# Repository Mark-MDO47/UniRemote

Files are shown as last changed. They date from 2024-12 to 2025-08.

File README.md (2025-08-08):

# UniRemote - one remote to rule them all!
I wanted a way to control all the projects I make.
- Note: it is not a remote for A/V systems. It is for my projects.

I wanted this to work not just at home in my WiFi zone but also at remote locations like a Maker Faire.<br>
It communicates with my projects via ESP-NOW WiFi
- https://docs.espressif.com/projects/esp-idf/en/stable/esp32/api-reference/network/esp_now.html

Current state of software and tools: **v1.0** "basics work: CYD, Tiny Code Reader for QRcodes, Mifare RC522 RF IC via MicroSD sniffer for 13.56MHz MIFARE Classic 1K cards, XPT2046_Bitbang lib to free up VSPI"

Here is a short YouTube demonstration of the latest version
- https://youtu.be/a9atNTkQOKo

This is the UniRemoteCYD breadboard setup with "drone style" batteries.
- I removed the QR code reader since the RFID reader was so easy to use
- The contactless RFID PICC cards (Proximity Integrated Circuit Card) are to the left
- The "drone style" battery charger and charging cable is at the top
- The XAIO ESP32-Sense target processor is below that, attached to a USB cable
- The Cheap Yellow Display (CYD) and its RFID sensor and batteries are on the bottom right
  - The red board sticking out at the bottom is the MicroSD Sniffer card used to communicate with the RFID sensor
- You can see more photos at https://github.com/Mark-MDO47/UniRemote/blob/master/photos.md
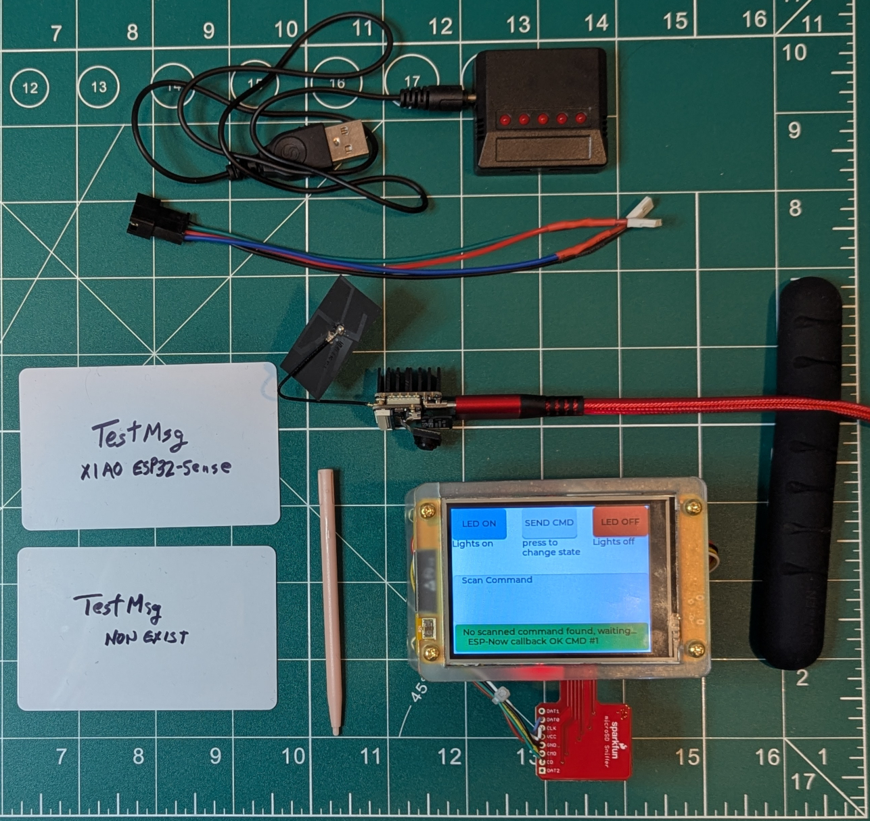
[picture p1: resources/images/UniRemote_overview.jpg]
Image of UniRemote breadboard overview


A little comic relief - the hilarious **Legendary Artifacts Club** by Elle Cordova https://www.youtube.com/shorts/GEJ_KPZY4n4

| One Remote to Rule Them All | I can bend countless devices to my will |
| --- | --- |
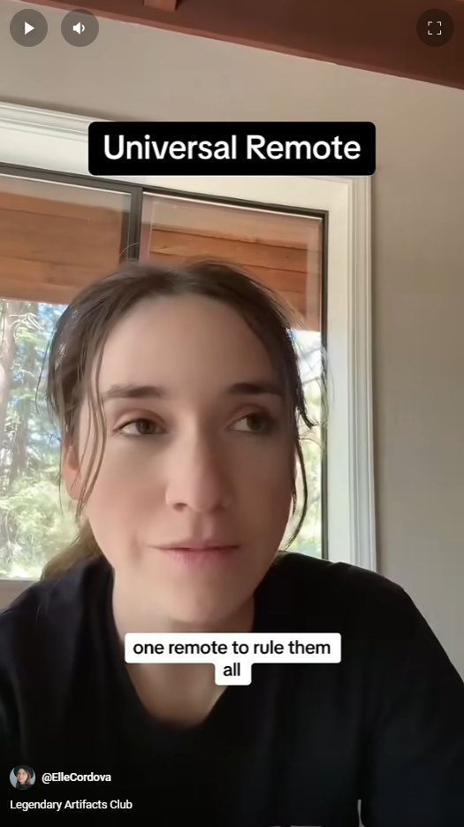
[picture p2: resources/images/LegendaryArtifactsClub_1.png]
Legendary Artifacts Club by Elle Cordova
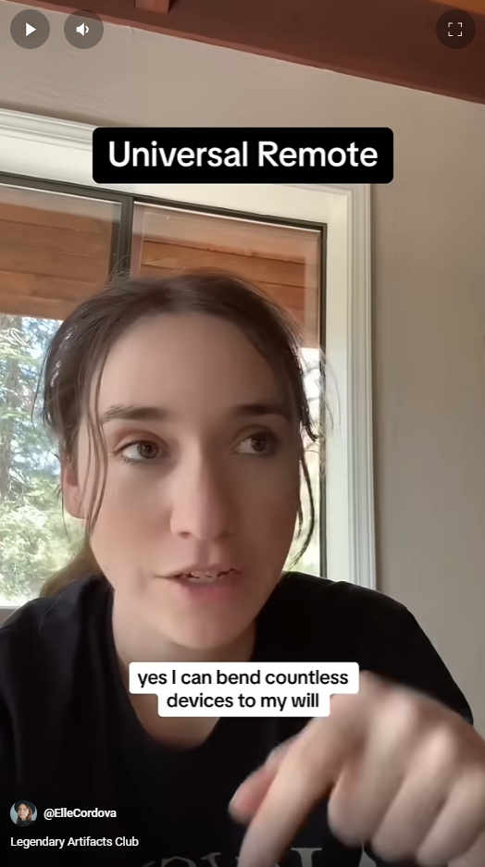
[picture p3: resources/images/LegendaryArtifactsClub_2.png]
Legendary Artifacts Club by Elle Cordova
|  |  |

**Table Of Contents**
* [Top](#uniremote-\--one-remote-to-rule-them-all "Top")
* [The Plan](#the-plan "The Plan")
* [Guide to the Code](#guide-to-the-code "Guide to the Code")
* [Schematic](#schematic "Schematic")
  * [Battery Harness](#battery-harness "Battery Harness")
* [Parts List](#parts-list "Parts List")
* [Interesting Considerations](#interesting-considerations "Interesting Considerations")
  * [General CYD and LVGL and Related Info](#general-cyd-and-lvgl-and-related-info "General CYD and LVGL and Related Info")
  * [DRAM_STR - Move Constant Strings to RAM instead of Program Storage](#dram_str-\--move-constant-strings-to-ram-instead-of-program-storage "DRAM_STR - Move Constant Strings to RAM instead of Program Storage")
  * [Entire Screen Pans or Scrolls](#entire-screen-pans-or-scrolls "Entire Screen Pans or Scrolls")
  * [LVGL Timeout and Crash if Call LVGL Routine inside ESP-NOW callback](#lvgl-timeout-and-crash-if-call-lvgl-routine-inside-esp\-now-callback "LVGL Timeout and Crash if Call LVGL Routine inside ESP-NOW callback")
  * [Do-It-Yourself Layout Creator](#do\-it\-yourself-layout-creator "Do-It-Yourself Layout Creator")
* [Licensing](#licensing "Licensing")

## The Plan
[Top](#uniremote-\--one-remote-to-rule-them-all "Top")<br>
My current thinking is to just use the RFID reader and leave out the QR code reader. Maybe add it back in later.

Because the MicroSD sniffer sticks out so far, I had planned to use removable 18650 batteries mounted on the side of the CYD to give it some protection. However, putting the 18650 batteries on the outside was trickier than I thought due to some connectors and components getting in the way. It also didn't provide much protection for the sniffer. I went ahead and put the Lipo "drone style" batteries in for now. There is a connector that allows me to charge the Lipo batteries without removing them.
- More details in the section [Battery Harness](#battery-harness "Battery Harness")

I have settled on the following hardware for the Universal Remote Control:
- CYD - Cheap Yellow Display
  - I am using the ESP32-2432S028R (Cheap Yellow Display or CYD) based on ESP32-D0WDQ6 controller.
  - I purchased this one: https://www.aliexpress.us/item/3256805697430313.html
  - This schematic might reflect the CYD: https://oshwlab.com/mariusmym/esp32_cyd_cheap_yellow_display
  - This gives an excellent CYD introduction: https://randomnerdtutorials.com/esp32-cheap-yellow-display-cyd-pinout-esp32-2432s028r
- RFID Reader
  - I am using the HiLetgo 3pcs RFID Kit - Mifare RC522 RF IC Card Sensor Module + S50 Blank Card + Key Ring
    - I purchased this one: https://www.amazon.com/dp/B07VLDSYRW
    - This doesn't support I2C or UART without board modifications; just SPI
      - look for Adrianotiger post #4 on Mar 2023 on https://forum.arduino.cc/t/esp32-rfid-rc522-i2c/1100200/3
      - here is webpage for the module including schematic https://www.sunrom.com/p/rfid-readerwriter-1356mhz-rc522-spi-module-with-cardkeychain
  - I am using the Meikuler 13.56MHz MIFARE Classic 1K, RFID Smart Cards / M1 Cards, ISO14443A Printable Blank RFID PVC Cards
    - I purchased this one: https://www.amazon.com/dp/B07S63VT7X
    - https://www.nxp.com/docs/en/data-sheet/MF1S50YYX_V1.pdf
    - A.K.A. PICC = Proximity Integrated Circuit Card (Contactless Card)
  - See following for more RFID Reader details:
    - https://github.com/Mark-MDO47/UniRemote/tree/master/code/RFIDRC522test
  - It took a bit of effort to use this with the CYD. I got a "sniffer" card to use the SPI pins in the CYD MicroSD slot, needed to do "bit banging" for touchscreen so could use hardware SPI for SD card.
    - I purchased this one: https://www.sparkfun.com/sparkfun-microsd-sniffer.html
    - https://github.com/sparkfun/MicroSD_Sniffer
    - Schematic https://cdn.sparkfun.com/datasheets/Tools/SparkFun_MicroSD_Sniffer_v10.pdf
    - https://github.com/Mark-MDO47/UniRemote/blob/master/code/RFIDRC522test/README.md

Will be trying these to see if they can be a more compact MicroSD sniffer:
- Nope: Extender cable 1: https://www.aliexpress.com/item/3256804754907124.html
- Nope: Extender cable 2: https://www.aliexpress.com/item/3256805782352551.html
- Nope: Alternative MicroSD sniffer to JTAG: https://shop.blinkinlabs.com/products/microsd-to-jtag-adapter-for-esp32

May use one or more of the following
- QR code reader
  - Tiny Code Reader from Useful Sensors
  - I purchased this one: https://www.sparkfun.com/products/23352
  - https://cdn.sparkfun.com/assets/e/9/d/9/f/TCR_Datasheet.pdf
  - https://github.com/usefulsensors/tiny_code_reader_docs/blob/main/README.md
  - https://github.com/usefulsensors/tiny_code_reader_arduino
- Alternative QR code readers
  - https://github.com/IndustrialArduino/NORVI-ESP32-CAMERA/tree/main/ESP32-CAMERA-QR_CODE_SCANNER_WITH_DISPLAY
  - https://randomnerdtutorials.com/esp32-cam-qr-code-reader-scanner-arduino/
- Voice Input - perhaps one of these
  - https://www.seeedstudio.com/XIAO-ESP32S3-Sense-p-5639.html
  - https://www.dfrobot.com/product-2665.html
- Joystick or rotary encoder, buttons
- BlueTooth keyboard

The hardware that receives the commands can use basically any ESP32 that includes WiFi.

## Guide to the Code
[Top](#uniremote-\--one-remote-to-rule-them-all "Top")<br>
Here is what the code is:<br>
| Link | Description |
| --- | --- |
| --- | **UNIREMOTE CODE** |
| [code/UniRemoteCYD](https://github.com/Mark-MDO47/UniRemote/tree/master/code/UniRemoteCYD "UniRemoteCYD") | "Cheap Yellow Display"-based UniRemote code sending ESP-NOW commands - attributions in the code.<br>Commands are input with either the QR code reader (I2C) or the RFID Reader (SPI via MicroSD sniffer).<br>To free up access to the CYD hardware VSPI port for the RFID Reader, the code uses the XPT2046_Bitbang software-based SPI library instead of the TFT_eSPI hardware based SPI library for the touchscreen.<br>This technique of using XPT2046_Bitbang for the touchscreen could alternatively be used to access the MicroSD card on the CYD if the MicroSD pins weren't being used for the RFID Reader. |
| [code/Uni_RW_PICC](https://github.com/Mark-MDO47/UniRemote/tree/master/code/Uni_RW_PICC "Uni PICC Rd/Wr") | UniRemote PICC read/write routines - attribution in the README |
| [code/CYDbitBangCalibrate](https://github.com/Mark-MDO47/UniRemote/tree/master/code/CYDbitBangCalibrate "CYDbitBangCalibrate") | Modified Random Nerds CYD Calibrate routine that uses the XPT2046_Bitbang software-based SPI library instead of the TFT_eSPI hardware based SPI library for the touchscreen - attributions in the code |
| [code/tiny_code_reader](https://github.com/Mark-MDO47/UniRemote/tree/master/code/tiny_code_reader "tiny_code_reader") | *.h file for using the QR code reader - attribution in its README<br>NOTE: not currently used in UniRemoteCYD |
| --- | **RECEIVER CODE** |
| [code/UniRemoteRcvrTemplate](https://github.com/Mark-MDO47/UniRemote/tree/master/code/UniRemoteRcvrTemplate "UniRemoteRcvrTemplate") | UniRemote code **template** for generic receiver of the commands - attributions in the code.<br>UniRemoteRcvrTemplate.ino shows an example of using UniRemoteRcvr.h and UniRemoteRcvr.cpp to receive ESP-NOW commands from UniRemoteCYD.<br>Also includes my adaptation of the ESP32 example **OTAWebUpdater.ino** Over-The-Air web updater **mdo_use_ota_webupdater**. |
| [code/mdo_use_ota_webupdater](https://github.com/Mark-MDO47/UniRemote/blob/master/code/mdo_use_ota_webupdater "mdo_use_ota_webupdater") |  My adaptation of the ESP32 example **OTAWebUpdater.ino** Over-The-Air web updater **mdo_use_ota_webupdater**. |
| [code/readMacAddress](https://github.com/Mark-MDO47/UniRemote/tree/master/code/readMacAddress "readMacAddress") | Code to read the WiFi MAC address of pretty much any ESP32 - used on remotes to get info - attribution in its README |
| --- | **UTILITIES** |
| [code/WriteRFID](https://github.com/Mark-MDO47/UniRemote/tree/master/code/WriteRFID "WriteRFID") | Used to **write** RFID cards using input text strings in same format as input to QRCode.py or **read** RFID cards - attributions in the code.<BR>Works on both UniRemoteCYD hardware and EPS32D special purpose hardware. |
| [MDOpythonUtils QRCode.py](https://github.com/Mark-MDO47/MDOpythonUtils/tree/master/QRCode "QRCode.py") | Python routine to generate QR code based on directions in a text file |
| --- | **DOCUMENTATION** |
| [code/CYDtest](https://github.com/Mark-MDO47/UniRemote/tree/master/code/CYDtest "CYDtest") | ESP32-2432S028R (Cheap Yellow Display or CYD) pointers to tutorials and hardware information |
| [code/RFIDRC522test](https://github.com/Mark-MDO47/UniRemote/tree/master/code/RFIDRC522test "RFIDRC522test")  | RFID RC522 pointers to tutorials and hardware information |
| --- | **DEPRECATED** |
| [code/UniRemote](https://github.com/Mark-MDO47/UniRemote/tree/master/code/UniRemote "UniRemote") | UniRemote code with QR code reader and **generic ESP32** module - attributions in the code. This is now **unused** and **deprecated**. I am switching to the CYD and the code in **UniRemoteCYD**. |
| [code/UniTestRcvr](https://github.com/Mark-MDO47/UniRemote/tree/master/code/UniTestRcvr "UniTestRcvr") | UniRemote code testbench for receiver of the commands - attributions in the code. This is now **unused** and **deprecated**. All further development for the receiver will go to the generic **UniRemoteRcvrTemplate**. |
| --- end of table --- | --- end of table --- |

## Schematic
[Top](#uniremote-\--one-remote-to-rule-them-all "Top")<br>
Connector P1 is some sort of JST connector. My best info on figuring this out is
- https://www.mattmillman.com/info/crimpconnectors/common-jst-connector-types/

This shows the connections to the CYD<br>
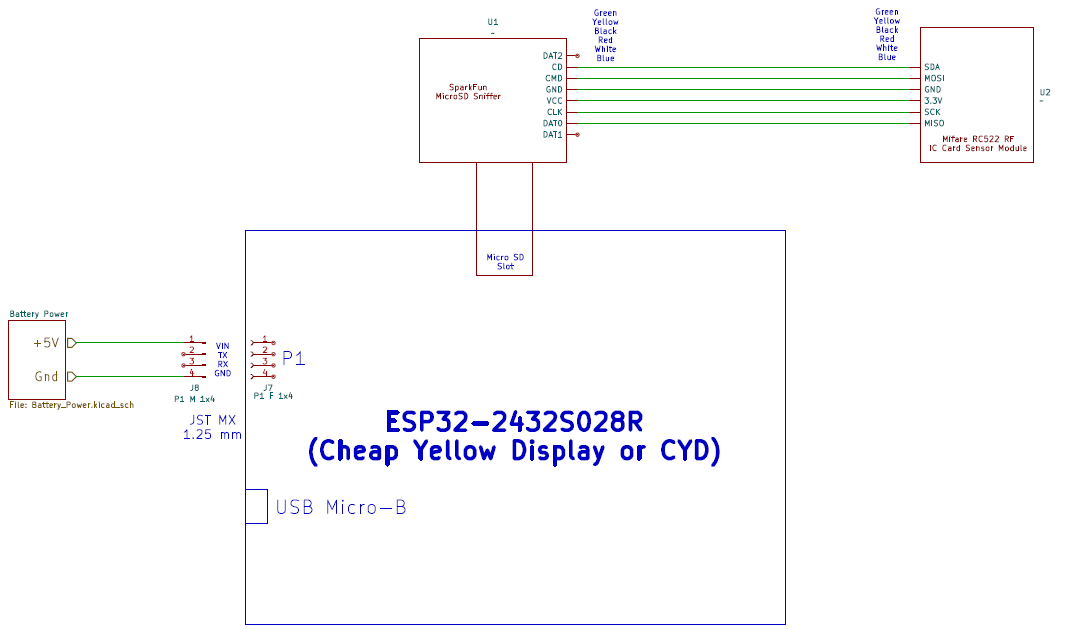
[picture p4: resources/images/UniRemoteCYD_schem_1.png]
Schematic of UniRemoteCYD showing CYD connections


This shows the connections to the batteries<br>
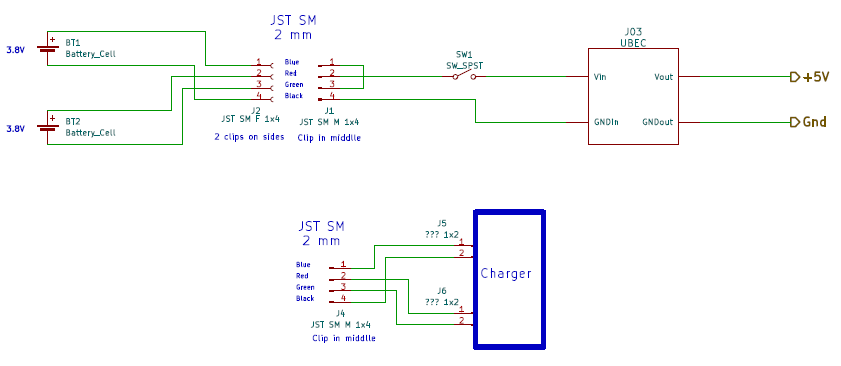
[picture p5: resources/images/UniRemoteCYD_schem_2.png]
Schematic of UniRemoteCYD showing Battery connections


### Battery Harness
[Top](#uniremote-\--one-remote-to-rule-them-all "Top")<br>
As mentioned above, I would like to come up with a more compact MicroSD sniffer arrangement. The fact that this sticks out so far has driven me to consider multiple ways to handle it in packaging, including the posibility of placing 18650 batteries on the sides to give it some protection.
- Alternatively I might use the two-wire interface to connect to another Arduino that connects to the RFID scanner, although that seems somewhat complicated. When I compare it to the time spent trying other options for MicroSD sniffers, the additional Arduino is looking better and better.

I chose to implement the fixed Lipo "drone style" batteries. There is a connector that can be used to disconnect the Lipo batteries from the UniRemote and connect to a charger without removing the batteries. Below is a diagram of the circuit.<br>
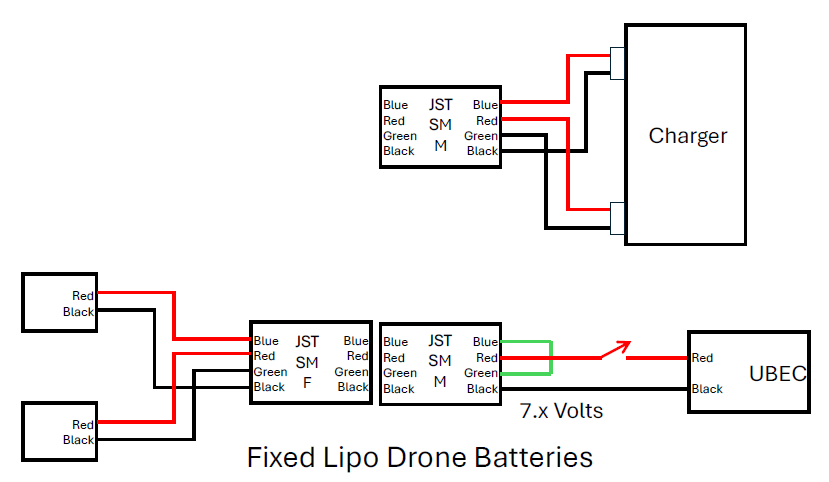
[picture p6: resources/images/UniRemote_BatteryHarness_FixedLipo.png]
Diagram for Fixed Lipo Battery Harness and Charger


Alternatively I did create a removable 18650 battery harness. Because these would be mounted on the sides of the CYD, the theory was that they would provide some protection for the MicroSD sniffer which sticks out on one side. In practice this did not seem as helpful as I hoped. Below is a diagram of the circuit.<br>
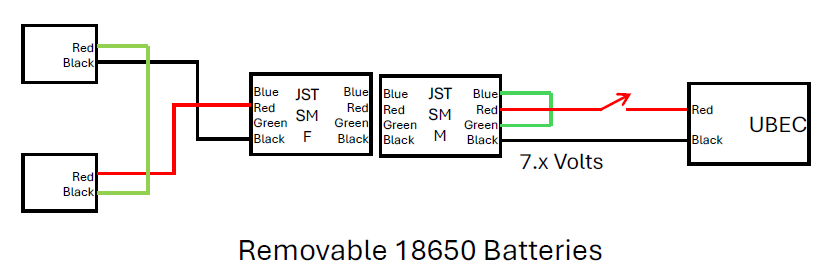
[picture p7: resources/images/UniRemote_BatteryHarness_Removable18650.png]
Diagram for Removable 18650 Battery Harness


## Parts List
[Top](#uniremote-\--one-remote-to-rule-them-all "Top")<br>
I finally got around to adding the parts list.

| Price (each) | Num | Description | URL |
| --- | --- | --- | --- |
| $11.00 | 1 | CYD ESP32 WiFi Bluetooth Development Board 2.8 Inch 240X320 TFT | https://www.aliexpress.us/item/3256805697430313.html |
| $3.33 | 1 | HiLetgo 3pcs RFID Kit - Mifare RC522 RF IC Card Sensor Module + S50 Blank Card | https://www.amazon.com/dp/B07VLDSYRW |
| $13.50 | 1 | SparkFun microSD Sniffer | https://www.sparkfun.com/sparkfun-microsd-sniffer.html |
| $0.20 | 1 | ON/Off Switch Self-Lock Micro Push Button Switch DC 30V 1A | https://www.amazon.com/gp/product/B086L2GPGX | $0.20 |
| $0.90 | 2 pair | 20 PCS JST MX 1.25 4-pin connector & wire (male/female) | https://www.amazon.com/dp/B09DYLY95R?th=1 |
| $0.30 | 2 pair | mxuteuk 20 Pairs 22 AWG JST SM Plug & wire (male/female) 150mm | https://www.amazon.com/dp/B083GR7FQF |
| $1.35 | 1 | CYD Case Only | https://www.aliexpress.us/item/3256806316808825.html |
| 0.10 | 8 | from 220 Pieces M3 Male Female Hex Brass Standoffs Spacers Screws Nuts Kit, Kindroufly Brass Standoffs Assortment Kit | https://www.amazon.com/dp/B0B3Y6WF2Y?th=1 |
| ??? | 2 | drone batteries and charger from my old parts bin | old parts bin |

## Interesting Considerations
[Top](#uniremote-\--one-remote-to-rule-them-all "Top")<br>
Following are things I wanted to document and remember.

### General CYD and LVGL and Related Info
[Top](#uniremote-\--one-remote-to-rule-them-all "Top")<br>

One key thing I found out was that all four of the ESP-32 hardware SPI ports are in use in the "standard" LVGL configuration. In order to use a hardware SPI port for the MicroSD slot, I had to use the XPT2046_Bitbang library instead of the TFT_eSPI library for the touchscreen.
- See https://github.com/Mark-MDO47/UniRemote/tree/master/code/RFIDRC522test for details.

| Description | URL |
| --- | --- |
| CYD Pinouts & Connectors | https://randomnerdtutorials.com/esp32-cheap-yellow-display-cyd-pinout-esp32-2432s028r |
| More CYD Pinouts in useful format | https://debugdiaries.co.uk/esp32-cheap-display-cyd-pinouts |
| CYD info in Japanese; need Google Translate but info looks quite good | https://macsbug.wordpress.com/2022/08/17/esp32-2432s028 |
| Info/Code for CYD and many variants | https://github.com/rzeldent/esp32-smartdisplay |
| --- | --- |
| RFID library I use | https://docs.arduino.cc/libraries/rfid_mfrc522v2 |
| LVGL and CYD | https://randomnerdtutorials.com/lvgl-cheap-yellow-display-esp32-2432s028r |
| LVGL and CYD | https://rntlab.com/module-1/esp32-lvgl-ebook |
| CYD and alternative library with lots of good info | https://github.com/witnessmenow/ESP32-Cheap-Yellow-Display.git|
| CYD LVGL interesting project | https://github.com/bitbank2/CYD_Projects.git<br>https://github.com/TheNitek/CYD-LVGL-Template.git |
| YouTube Ralph S. Bacon "#203 SPIFFS vs LITTLEFS for ESP32 & ESP8266 (not Arduino UNO)" | https://www.youtube.com/watch?v=4r6YZlLfKfw |
| --- | --- |
| Espressif ESP32 example using non-standard SPI pins | https://docs.espressif.com/projects/arduino-esp32/en/latest/api/spi.html |
| Using bit-banging so touch and SD can work in same program | https://github.com/witnessmenow/ESP32-Cheap-Yellow-Display/blob/main/TROUBLESHOOTING.md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 |

### DRAM_STR - Move Constant Strings to RAM instead of Program Storage
[Top](#uniremote-\--one-remote-to-rule-them-all "Top")<br>
Since I am using an ESP-32 CYD with WiFi and LVGL, there is a lot of code included in libraries and I quickly ran to the limits of program storage versus RAM.
```
Sketch uses 1208557 bytes (92%) of program storage space. Maximum is 1310720 bytes.
Global variables use 61544 bytes (18%) of dynamic memory, leaving 266136 bytes for local variables. Maximum is 327680 bytes.
```
I discovered that I need to do the opposite of what I do with the Arduino Nano. I need use the "DRAM_STR" macro to move constant strings (easiest to find) from program storage into dynamic memory. On the Arduino Nano it was often helpful to use the "F" macro to move constant strings in the other direction since the dynamic memory was so limited.

### Entire Screen Pans or Scrolls
[Top](#uniremote-\--one-remote-to-rule-them-all "Top")<br>
I didn't find a good way to prevent the entire screen from "panning" or "scrolling" during a "long press". I tried the following without success.

| Routine | Description |
| --- | --- |
| void lv_indev_set_long_press_time(lv_indev_t * indev, uint16_t long_press_time); | Setting value to 65,535 after creating indev did not help |
| void lv_indev_reset_long_press(lv_indev_t * indev); | Calling within indev read_cb function (cyd_input_read() in my code) when .tirqTouched() or .touched() caused buttons to not operate |

### LVGL Timeout and Crash if Call LVGL Routine inside ESP-NOW callback
[Top](#uniremote-\--one-remote-to-rule-them-all "Top")<br>
I guess I should have predicted that a callback, which is somewhat similar to an interrupt routine, shouldn't assume it can call a lot of routines that might not be re-entrant.
- Result - just set flags in callback routines, do the work of the flags in loop() and its routines.

The symptom was:
- If I did ESP-NOW messages (using PICC card as the source) for which the receiver was present and receiving, I could seemingly send as many as I wanted with the physical scanning of a PICC card giving a timing interval.
- If I did 2 or sometimes up to 3 ESP-NOW messages with no receiver, even if done quite slowly, the CYD would get an LVGL watchdog timer timeout and then it would crash and reboot.

It was a little mysterious because the processing was the same for both of them, only the status message itself was different.

My **guess** at the mechanism is:
- If the receiver was present, the response was so quick that the LVGL routines were not doing anything when the ESP-NOW send callback routine was called.
- If the receiver was absent, the response was a timeout and this could happen when the loop and/or LVGL refresh was happening so problem if calling non-reentrant LVGL routine from ESP-NOW send callback.

### Do-It-Yourself Layout Creator
[Top](#uniremote-\--one-remote-to-rule-them-all "Top")<br>
I didn't know about this when I did my perfboard design for [code/WriteRFID](https://github.com/Mark-MDO47/UniRemote/tree/master/code/WriteRFID "WriteRFID") but I wish I had used DIYLC instead of hacking away at my perfboard!
- https://github.com/bancika/diy-layout-creator
- https://github.com/bancika/diy-layout-creator/releases

Here is a nice YouTube showing how to use it
- Design Circuits on Stripboard or Veroboard for FREE with DIY Layout Creator by TekSparkz - https://www.youtube.com/watch?v=mzje3eHqi2E

## Licensing
[Top](#uniremote-\--one-remote-to-rule-them-all "Top")<br>
This repository has a LICENSE file for Apache 2.0. There may be code included that I have modified from other open sources (such as Arduino, Espressif, SparkFun, Seeed Studio, DFRobot, RandomNerds, etc.). These other sources may possibly be licensed using a different license model. In such a case I will include some notation of this. Typically I will include verbatim the license in the included/modified source code, but alternatively there might be a LICENSE file in the source code area that points out exceptions to the Apache 2.0 license.

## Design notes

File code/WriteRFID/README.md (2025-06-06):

# WriteRFID

**Table Of Contents**
* [Top](#writerfid "Top")
* [Arduino IDE Board Selection](#arduino-ide-board-selection "Arduino IDE Board Selection")
  * [Do-It-Yourself Layout Creator](#do\-it\-yourself-layout-creator "Do-It-Yourself Layout Creator")
* [Description](#description "Description")
* [Example Run of WriteRFID](#example-run-of-writerfid "Example Run of WriteRFID")

## Arduino IDE Board Selection
[Top](#WriteRFID "Top")<br>
The same setup works for both hardware platforms. In the Arduino IDE, select the board as "ESP32 Dev Module".

WriteRFID has been run on two different hardware platforms
- UniRemote_CYD
  - Based on ESP32-2432S028R (Cheap Yellow Display or CYD). The CYD is based on the ESP32 D0WDQ6.
  - UniRemoteCYD includes other hardware, especially a "sniffer" on the MicroSD slot connecting the VSPI port to the Mifare RC522 RF IC Card Sensor Module.
  - https://github.com/Mark-MDO47/UniRemote/blob/master/README.md
- Special purpose ESP32D hardware
  - Based on an ESP32D processor embedded in a module that seems to be based on the ESP32-WROOM-32D Devkit C
    - https://docs.espressif.com/projects/esp-idf/en/latest/esp32/hw-reference/esp32/get-started-devkitc.html
  - Also connects the VSPI port to the Mifare RC522 RF IC Card Sensor Module.
  - https://github.com/Mark-MDO47/UniRemote/blob/master/code/WriteRFID/ESP32D_HW.md

| UniRemoteCYD | ESP32D HW |
| --- | --- |
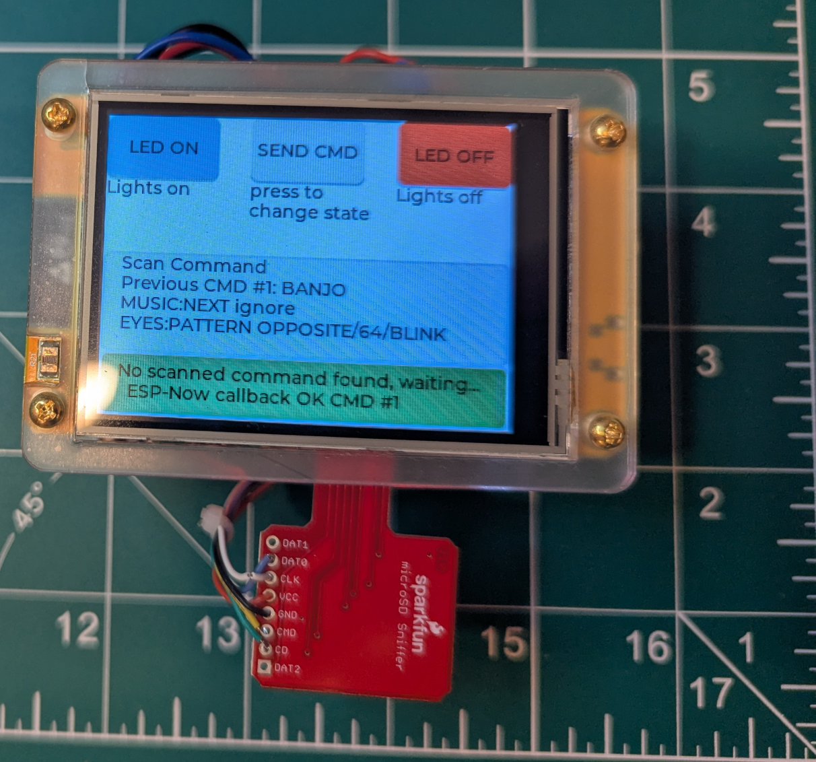
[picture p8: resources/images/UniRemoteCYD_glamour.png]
The UniRemoteCYD
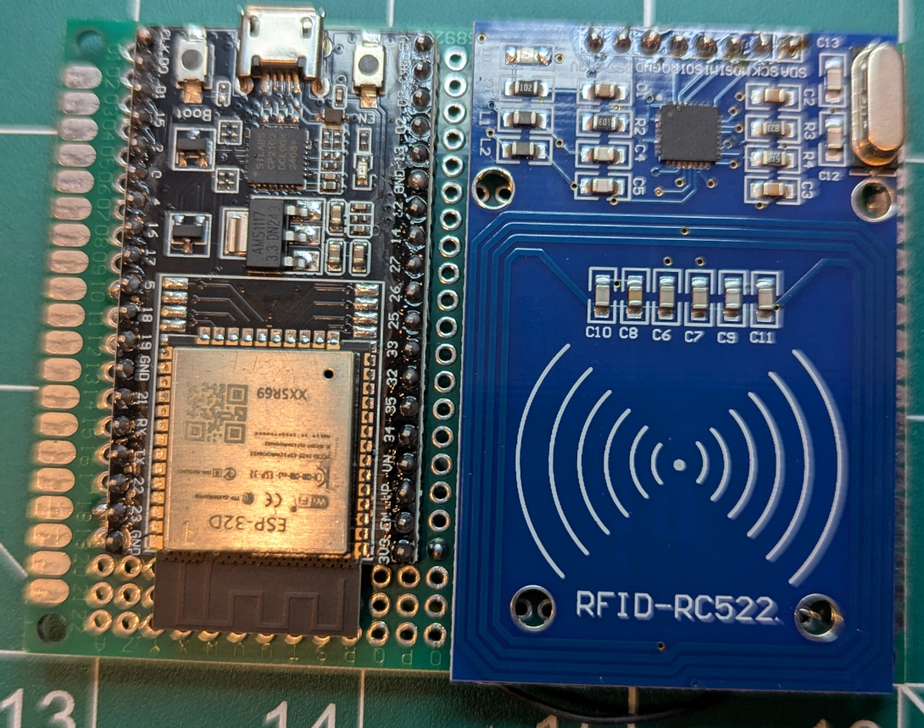
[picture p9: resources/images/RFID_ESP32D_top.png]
ESP32D Special Hardware
|  |  |

This diagram shows the pin connections to the RC522 RFID reader/writer for both hardware configurations. In the case of UniRemoteCYD, the connections go through the MicroSD slot and a sniffer card. The actual GPIO pin connections are the same in both cases.

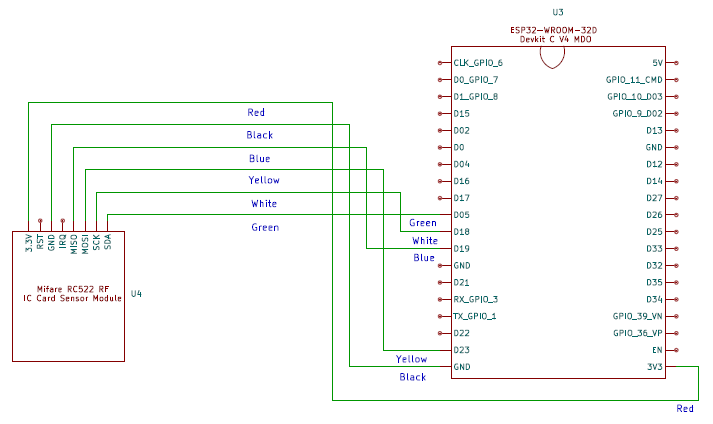
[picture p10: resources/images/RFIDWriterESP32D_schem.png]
ESP32D Special Hardware schematic


### Do-It-Yourself Layout Creator
[Top](#uniremote-\--one-remote-to-rule-them-all "Top")<br>
I didn't know about this when I did my perfboard design for the Special purpose ESP32D hardware for WriteRFID but I wish I had used DIYLC instead of hacking away at my perfboard!
- https://github.com/bancika/diy-layout-creator
- https://github.com/bancika/diy-layout-creator/releases

Here is a nice YouTube showing how to use it
- Design Circuits on Stripboard or Veroboard for FREE with DIY Layout Creator by TekSparkz - https://www.youtube.com/watch?v=mzje3eHqi2E

## Description
[Top](#WriteRFID "Top")<br>
This routine writes and checks command info to PICC (RFID) cards. It can also read PICC cards without writing them, but assumes they contain an ASCII string.<br>
It is intended to write and/or read PICC cards to be used by UniRemoteCYD.
- https://github.com/Mark-MDO47/UniRemote
- https://github.com/Mark-MDO47/UniRemote/tree/master/code/UniRemoteCYD

This routine runs on ESP32-2432S028R (Cheap Yellow Display or CYD) using
the same hardware setup as UniRemoteCYD, with a "sniffer" on the MicroSD
slot connecting the VSPI port to the Mifare RC522 RF IC Card Sensor Module.

This unmodified routine also runs on the specialized ESP32D hardware described in [Arduino IDE Board Selection](#arduino-ide-board-selection "Arduino IDE Board Selection")

The dialog with the operator is done using the serial port, not the display
and touchscreen. Because I am lazy and also because the specialized ESP32D hardware doesn't have a display.

The PICC command info is entered in array write_strings[] in the code before running WriteRFID.
The text in write_strings[] is the same format as the input file to QRCode.py
- https://github.com/Mark-MDO47/MDOpythonUtils/tree/master/QRCode

The command is a one-line zero-terminated ASCII string (without line end) of the following form
```
Example: "BANJO\tMessage for BANJO\tac:67:b2:2c:c9:c0|BANJO ; MUSIC:NEXT ignore ; EYES:PATTERN OPPOSITE/64/BLINK"
<destination>\t<description>\t<WiFiMACaddress>|<destination> ; <command, perhaps broken up with colon> <parameters, perhaps broken up with forward slash> { optional further  "; <command> <parameters>" triplets }
   <destination>: a human readable name for the target
   <description>: a human readable summary of the command(s)
   <WiFiMACaddress>: the ESP-NOW WiFi MAC address of the destination - 6 hexadecimal bytes separated with colon, case insensitive
   <destination>: a human readable name for the target that will display on UniRemoteCYD
   ; - semicolon surrounded by spaces starts each command
   <commmand>: a command for the destination. Optionally broken up with colon ":"
   <parameters>: one or more parameters for the command. If more than one parameter, broken up with forward slash "/". If no parameters are needed, still one must be provided - see "ignore" above.
```

## Example Run of WriteRFID
[Top](#WriteRFID "Top")<br>
```
starting WriteRFID - writes to and/or reads from a PICC RFID card
   see https://github.com/Mark-MDO47/UniRemote

Prepare to write MIFARE Classic EV1 1K card
   Enter anything starting with r or R to start looking for card and read/display it
   Enter anything starting with w or W to start looking for card and writing below write string
   Enter anything starting with s or S to skip below write string and go to the next
   Enter anything starting with a or A to abort this process and stop writing RFID cards
 --String-To-Process--> "Message for BANJO	ac:67:b2:2c:c9:c0|BANJO ; MUSIC:SONG A440"
Enter your command to process this String >  
You Entered "w"
 --Write--> "ac:67:b2:2c:c9:c0|BANJO ; MUSIC:SONG A440"
Please place card on writer
--READING---------
Card UID:  41 84 A5 82
PICC Write final MFRC522 status 0
uni_write_picc() succesful! Please remove card, short wait, replace card for reading
--READING---------
Card UID:  41 84 A5 82
PICC read final MFRC522 status 0
 --Read---> "ac:67:b2:2c:c9:c0|BANJO ; MUSIC:SONG A440"
Comparison GOOD - Read data matches Write data
Please remove PICC card

Prepare to write MIFARE Classic EV1 1K card
   Enter anything starting with r or R to start looking for card and read/display it
   Enter anything starting with w or W to start looking for card and writing below write string
   Enter anything starting with s or S to skip below write string and go to the next
   Enter anything starting with a or A to abort this process and stop writing RFID cards
 --String-To-Process--> "Message for BANJO	ac:67:b2:2c:c9:c0|BANJO ; VOLUME:GSCALE 50"
Enter your command to process this String > 
You Entered "r"
Please place card to read on reader (AKA writer)
--READING---------
Card UID:  72 1C EE AC
PICC read final MFRC522 status 0
 --Read---> "ac:67:b2:2c:c9:c0|BANJO ; MUSIC:NEXT ignore ; EYES:PATTERN OPPOSITE/64/BLINK"
Please remove PICC card
   and enter R or r to read another
    or enter M or m to go to main menu
Enter your command >  
You Entered "r"
Please place card to read on reader (AKA writer)
--READING---------
Card UID:  F1 9B A4 82
PICC read final MFRC522 status 0
 --Read---> "ac:67:b2:2c:c9:c0|BANJO ; MUSIC:TYPE CHRISTMAS"
Please remove PICC card
   and enter R or r to read another
    or enter M or m to go to main menu
Enter your command >  
You Entered "m"
Prepare to write MIFARE Classic EV1 1K card
   Enter anything starting with r or R to start looking for card and read/display it
   Enter anything starting with w or W to start looking for card and writing below write string
   Enter anything starting with s or S to skip below write string and go to the next
   Enter anything starting with a or A to abort this process and stop writing RFID cards
 --String-To-Process--> "Message for BANJO	ac:67:b2:2c:c9:c0|BANJO ; VOLUME:GSCALE 50"
Enter your command to process this String >  
You Entered "s"
Skipping to next string

Prepare to write MIFARE Classic EV1 1K card
   Enter anything starting with r or R to start looking for card and read/display it
   Enter anything starting with w or W to start looking for card and writing below write string
   Enter anything starting with s or S to skip below write string and go to the next
   Enter anything starting with a or A to abort this process and stop writing RFID cards
 --String-To-Process--> "Message for BANJO	ac:67:b2:2c:c9:c0|BANJO ; VOLUME:GSCALE 150"
Enter your command to process this String >  
You Entered "a"
Aborting; done
```

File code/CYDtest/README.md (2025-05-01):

# Cheap Yellow Display (CYD) testing

**Table Of Contents**
* [Top](#cheap-yellow-display-(cyd)-testing "Top")
* [Hardware](#hardware "Hardware")
* [Tutorials and Courses](#tutorials-and-courses "Tutorials and Courses")

## Hardware
[Top](#cheap-yellow-display-(cyd)-testing "Top")<br>
I am using the ESP32-2432S028R (Cheap Yellow Display or CYD) based on ESP32-D0WDQ6 controller. The display I am using was purchased here:
- https://www.aliexpress.us/item/3256805697430313.html

In the Arduino IDE, select the board as "ESP32 Dev Module". The CYD is based on the ESP32 D0WDQ6.

## Tutorials and Courses
[Top](#cheap-yellow-display-(cyd)-testing "Top")<br>
For starters, I am using these Random Nerd tutorials:
- https://randomnerdtutorials.com/cheap-yellow-display-esp32-2432s028r/
- https://randomnerdtutorials.com/touchscreen-on-off-button-cheap-yellow-display-esp32-2432s028r/
- https://randomnerdtutorials.com/lvgl-cheap-yellow-display-esp32-2432s028r/
- https://randomnerdtutorials.com/esp32-cheap-yellow-display-cyd-pinout-esp32-2432s028r/

Then I downloaded this Random Nerd course Ebook and materials:
- https://rntlab.com/module-1/esp32-lvgl-ebook/

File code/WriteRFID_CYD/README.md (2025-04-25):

# WriteRFID_CYD

**Table Of Contents**
* [Top](#writerfid_cyd "Top")
* [Arduino IDE Board Selection](#arduino-ide-board-selection "Arduino IDE Board Selection")
* [Description](#description "Description")
* [Example Run of WriteRFID_CYD](#example-run-of-writerfid_cyd "Example Run of WriteRFID_CYD")

## Arduino IDE Board Selection
[Top](#writerfid_cyd "Top")<br>
In the Arduino IDE, select the board as "ESP32 Dev Module". The CYD is based on the ESP32 D0WDQ6.

## Description
[Top](#writerfid_cyd "Top")<br>
This routine writes and checks command info to PICC (RFID) cards.
It is intended to write PICC cards to be used by UniRemoteCYD.
- https://github.com/Mark-MDO47/UniRemote
- https://github.com/Mark-MDO47/UniRemote/tree/master/code/UniRemoteCYD

This routine runs on ESP32-2432S028R (Cheap Yellow Display or CYD) using
the same hardware setup as UniRemoteCYD, with a "sniffer" on the MicroSD
slot connecting the VSPI port to the Mifare RC522 RF IC Card Sensor Module.

The dialog with the operator is done using the serial port, not the display
and touchscreen. Because I am lazy.

The PICC command info is entered in array write_strings[] in the code before running.
The text in write_strings[] is the same format as the input file to QRCode.py
- https://github.com/Mark-MDO47/MDOpythonUtils/tree/master/QRCode

The command is a one-line zero-terminated ASCII string (without line end) of the following form
```
Example: "BANJO\tMessage for BANJO\tac:67:b2:2c:c9:c0|BANJO ; MUSIC:NEXT ignore ; EYES:PATTERN OPPOSITE/64/BLINK"
<destination>\t<description>\t<WiFiMACaddress>|<destination> ; <command, perhaps broken up with colon> <parameters, perhaps broken up with forward slash> { optional further  "; <command> <parameters>" triplets }
   <destination>: a human readable name for the target
   <description>: a human readable summary of the command(s)
   <WiFiMACaddress>: the ESP-NOW WiFi MAC address of the destination - 6 hexadecimal bytes separated with colon, case insensitive
   <destination>: a human readable name for the target that will display on UniRemoteCYD
   ; - semicolon surrounded by spaces starts each command
   <commmand>: a command for the destination. Optionally broken up with colon ":"
   <parameters>: one or more parameters for the command. If more than one parameter, broken up with forward slash "/". If no parameters are needed, still one must be provided - see "ignore" above.
```

## Example Run of WriteRFID_CYD
[Top](#writerfid_cyd "Top")<br>
```
starting WriteRFID_CYD - writes to a PICC RFID card
   see https://github.com/Mark-MDO47/UniRemote

Prepare to write MIFARE Classic EV1 1K card
   Enter anything starting with w or W to start looking for card and writing
   Enter anything starting with s or S to skip this string and go to the next
   Enter anything starting with a or A to abort this process and stop writing RFID cards
 --String-To-Process--> "Test Message to XIAO ESP32-Sense	74:4d:bd:98:7f:1c|TestMessage XIAO ESP32-Sense"
Enter your command to process this String >  
You Entered "Skip"
Skipping to next string

Prepare to write MIFARE Classic EV1 1K card
   Enter anything starting with w or W to start looking for card and writing
   Enter anything starting with s or S to skip this string and go to the next
   Enter anything starting with a or A to abort this process and stop writing RFID cards
 --String-To-Process--> "Test Message to non-existing destination	74:4d:bd:11:11:11|TestMessage non-existing"
Enter your command to process this String >  
You Entered "write"
 --Write--> "74:4d:bd:11:11:11	TestMessage non-existing	Test Message to non-existing destination"
Please place card on writer
--READING---------
Card UID:  13 6A 98 20
PICC Write final MFRC522 status 0
uni_write_picc() succesful! Please remove card, short wait, replace card for reading
--READING---------
Card UID:  13 6A 98 20
PICC read final MFRC522 status 0
 --Read---> "74:4d:bd:11:11:11	TestMessage non-existing	Test Message to non-existing destination"
Comparison GOOD - Read data matches Write data
Please remove PICC card

Prepare to write MIFARE Classic EV1 1K card
   Enter anything starting with w or W to start looking for card and writing
   Enter anything starting with s or S to skip this string and go to the next
   Enter anything starting with a or A to abort this process and stop writing RFID cards
 --String-To-Process--> "Test Message is too short	74:4d:bd:11:11:1|TestMessage address too short"
Enter your command to process this String >  
You Entered "abort"
Aborting; done
```

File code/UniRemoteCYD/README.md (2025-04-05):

# UniRemoteCYD software - one remote to rule them all!

**Table Of Contents**
* [Top](#uniremotecyd-software-\--one-remote-to-rule-them-all "Top")
* [Arduino IDE Board Selection](#arduino-ide-board-selection "Arduino IDE Board Selection")
* [Expected Flow for V1.0](#expected-flow-for-v10 "Expected Flow for V1.0")
* [Licensing](#licensing "Licensing")

## Arduino IDE Board Selection
[Top](#uniremote-\--one-remote-to-rule-them-all "Top")<br>
In the Arduino IDE, select the board as "ESP32 Dev Module". The CYD is based on the ESP32 D0WDQ6.

## Expected Flow for V1.0
[Top](#uniremote-\--one-remote-to-rule-them-all "Top")<br>

**UNI_STATE_WAIT_CMD**
- *last cmd all done, wait for next cmd (probably QR but any source OK)*
- alert OK for next CMD
- wait for CMD
  - if not "too soon"
    - scan CMD code into RAM

**UNI_STATE_CMD_SEEN**
- *command in queue, waiting for GO or CLEAR*
- alert wait for send
- wait for SEND or CLEAR
  - if receive CLEAR, clear cmd and go to WAIT_CMD
  - if receive SEND, go to SENDING

**UNI_STATE_SENDING_CMD**
- *command being sent (very short state)*
- alert that SENDING
- send command
  - check if too soon, go to UNI_STATE_SHOW_STAT
  - check MAC addr validity & able to register MAC peer; if error go to SHOW_STAT
  - call send ESP-NOW routine
    - if OK go to WAIT_CB
    - if error go to SHOW_STAT

**UNI_STATE_WAIT_CB**
- *waiting for send callback (very short state)*
- alert that WAIT_CB
- wait for callback
  - if timeout or bad, go to SHOW_STAT
  - if OK, go to WAIT_CMD

**UNI_STATE_SHOW_STAT**
- *show error status and allow cmd abort*
- alert that SHOW_STAT
- wait for SEND or ABORT
  - if receive ABORT, clear cmd and go to WAIT_CMD
  - if receive SEND, go to SENDING

## Licensing
[Top](#uniremote-\--one-remote-to-rule-them-all "Top")<br>
This repository has a LICENSE file for Apache 2.0. There may be code included that I have modified from other open sources (such as Arduino, Espressif, SparkFun, Seeed Studio, DFRobot, RandomNerds, etc.). These other sources may possibly be licensed using a different license model. In such a case I will include some notation of this. Typically I will include verbatim the license in the included/modified source code, but alternatively there might be a LICENSE file in the source code area that points out exceptions to the Apache 2.0 license.

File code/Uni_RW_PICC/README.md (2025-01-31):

# Uni_RW_PICC - routines to read/write PICC cards for UniRemote

## Attributions

This code was developed after reading the Random Nerd Tutorials below.<br>

There are significant differences in this code and the tutorials,
but I want to give a tip of the hat to Rui Santos & Sara Santos for the
wonderful work they do.

Below is the attribution from the Random Nerd Tutorial esp32-mfrc522-rfid-reader-arduino.
```
/*
  Rui Santos & Sara Santos - Random Nerd Tutorials
  Complete project details at https://RandomNerdTutorials.com/esp32-mfrc522-rfid-reader-arduino/
  Permission is hereby granted, free of charge, to any person obtaining a copy of this software and associated documentation files.  
  The above copyright notice and this permission notice shall be included in all copies or substantial portions of the Software.
*/
```

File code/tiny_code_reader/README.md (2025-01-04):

# tiny_code_reader.h

THIS CODE CAME FROM Useful Sensors https://github.com/usefulsensors/tiny_code_reader_arduino.git

See inside the .h file for a copy of the LICENSE

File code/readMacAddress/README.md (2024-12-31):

# readMacAddress - how to get the MAC Address to use in commands from UniRemote

This code is pretty much verbatim from Rui Santos & Sara Santos - Random Nerd Tutorials
- https://RandomNerdTutorials.com/get-change-esp32-esp8266-mac-address-arduino/

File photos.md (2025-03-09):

# Photos

**Table Of Contents**
* [Top](#photos "Top")
* [Latest Photos - Breadboard](#latest-photos-\--breadboard "Latest Photos - Breadboard")
* [Previous Photos - Initial Breadboard](#previous-photos-\--initial-breadboard "Previous Photos - Initial Breadboard")

## Latest Photos - Breadboard
[Top](#photos "Top")<br>
This is the UniRemoteCYD breadboard setup with "drone style" batteries.
- I removed the QR code reader since the RFID reader was so easy to use
- The contactless RFID PICC cards (Proximity Integrated Circuit Card) are to the left
- The "drone style" battery charger and charging cable is at the top
- The XAIO ESP32-Sense target processor is below that, attached to a USB cable
- The Cheap Yellow Display (CYD) and its RFID sensor and batteries are on the bottom right
  - The red board sticking out at the bottom is the MicroSD Sniffer card used to communicate with the RFID sensor

Image of UniRemote breadboard overview

Image of UniRemote breadboard - bottom.
- The blue module towards the left is the RFID sensor.
- The black blob on the right is the on/off switch.
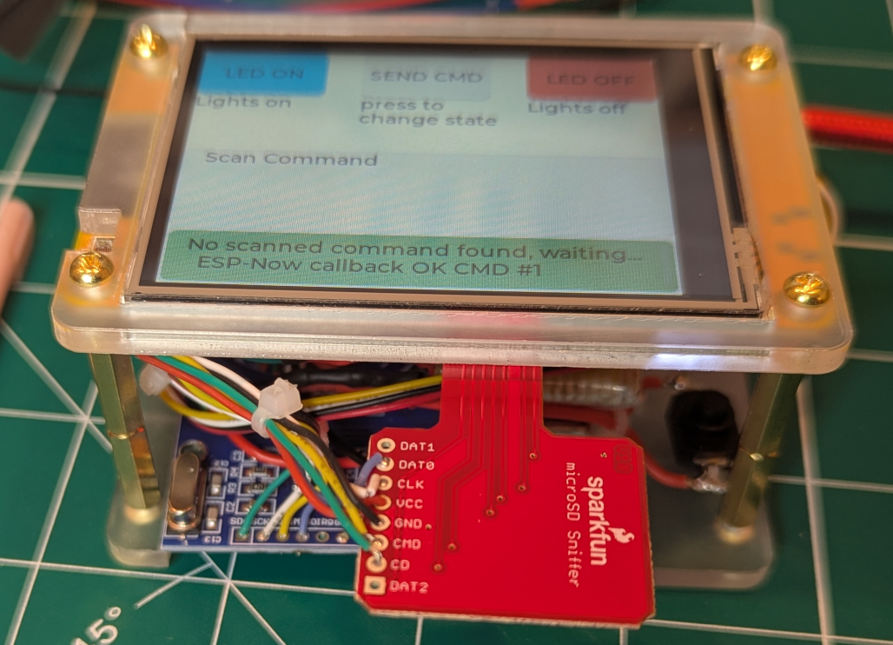
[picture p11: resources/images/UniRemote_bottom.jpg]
Image of UniRemote breadboard bottom


Image of UniRemote breadboard - top
- The silvery things on the left are the "drone style" Lipo batteries.
- The blue module towards the right is the RFID sensor.
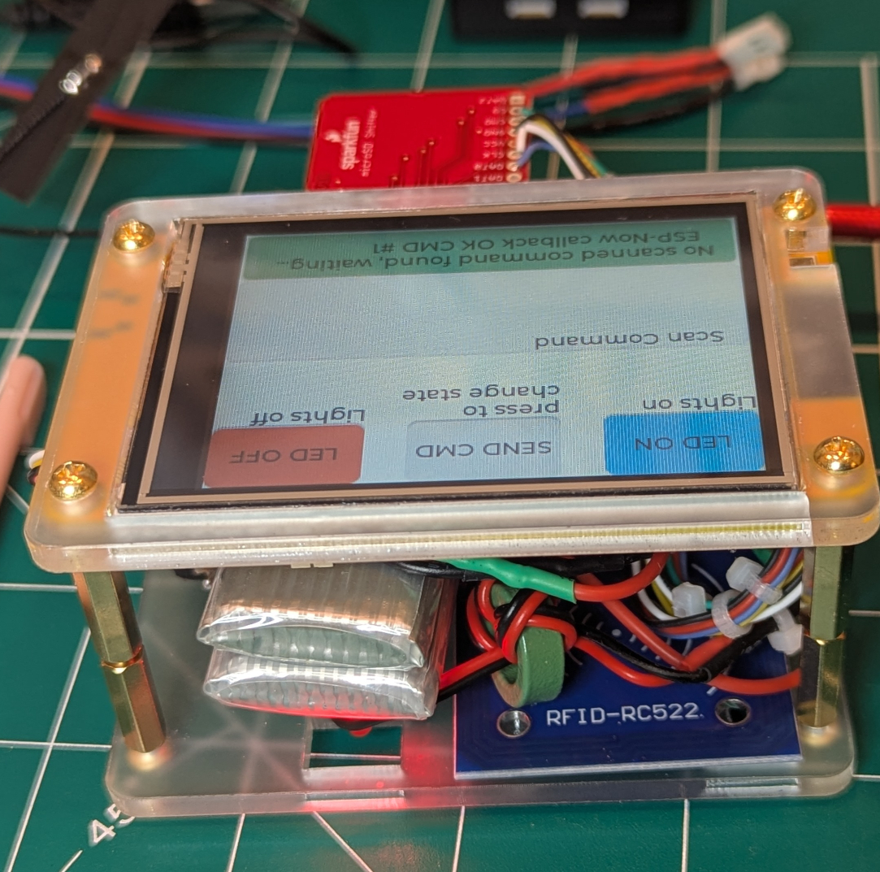
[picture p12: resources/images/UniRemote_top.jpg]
Image of UniRemote breadboard top


Image of UniRemote breadboard interior from bottom<br>
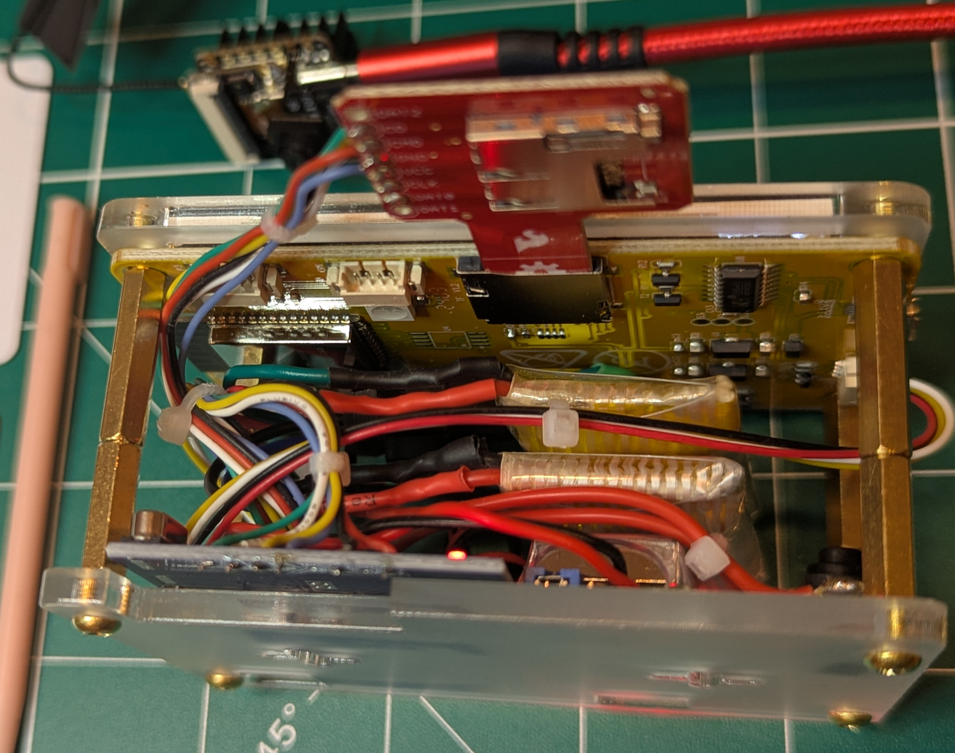
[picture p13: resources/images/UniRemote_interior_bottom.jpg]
Image of UniRemote breadboard interior from bottom


Image of UniRemote breadboard interior from left<br>
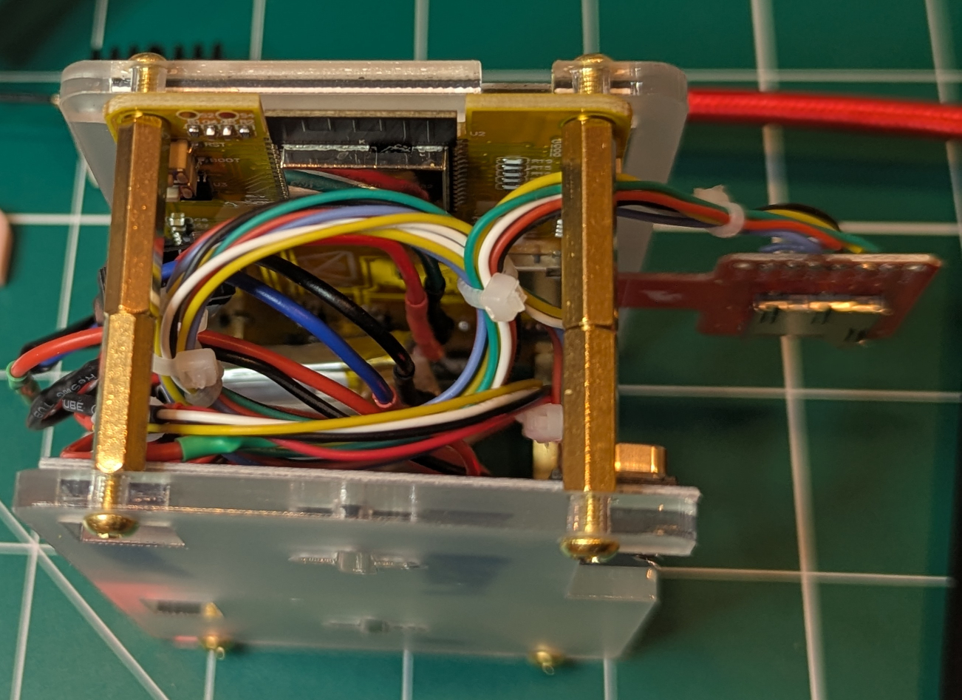
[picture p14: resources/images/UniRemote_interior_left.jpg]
Image of UniRemote breadboard interior from left


Image of UniRemote breadboard interior from right
- This gives a good view of the black on/off button in the foreground
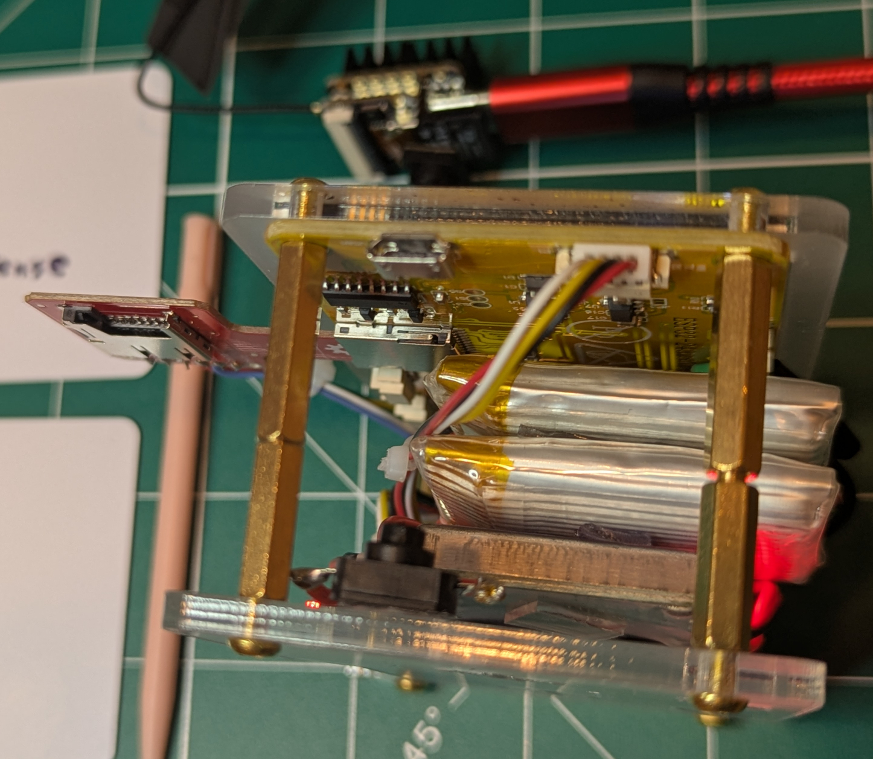
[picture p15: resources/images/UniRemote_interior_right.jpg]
Image of UniRemote breadboard interior from right


## Previous Photos - Initial Breadboard
[Top](#photos "Top")<br>
Here is my breadboard setup with the Cheap Yellow Display, the QR code reader and the RFID reader.<br>
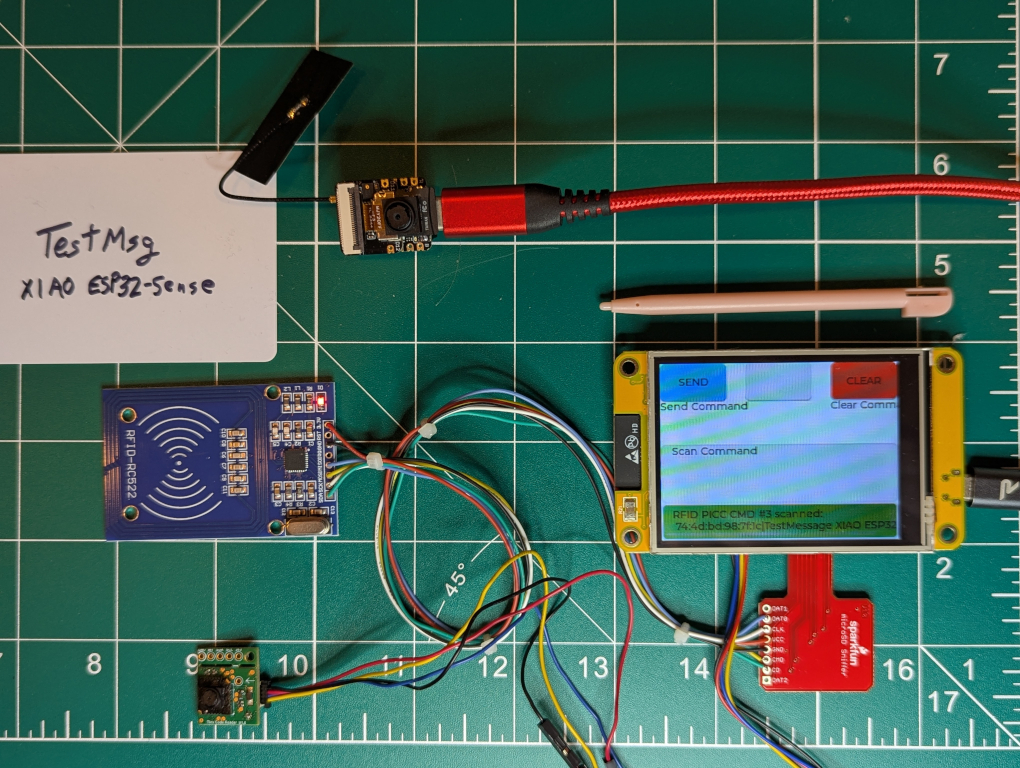
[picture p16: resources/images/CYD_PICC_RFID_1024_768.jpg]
breadboard setup with the Cheap Yellow Display, the QR code reader and the RFID reader


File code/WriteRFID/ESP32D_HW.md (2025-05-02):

# WriteRFID ESP32D Hardware

Schematic for WriteRFID ESP32D hardware<br>
Schematic for WriteRFID<br>
Top View of WriteRFID ESP32D hardware<br>
Top View of WriteRFID<br>
Bottom View of WriteRFID ESP32D hardware<br>
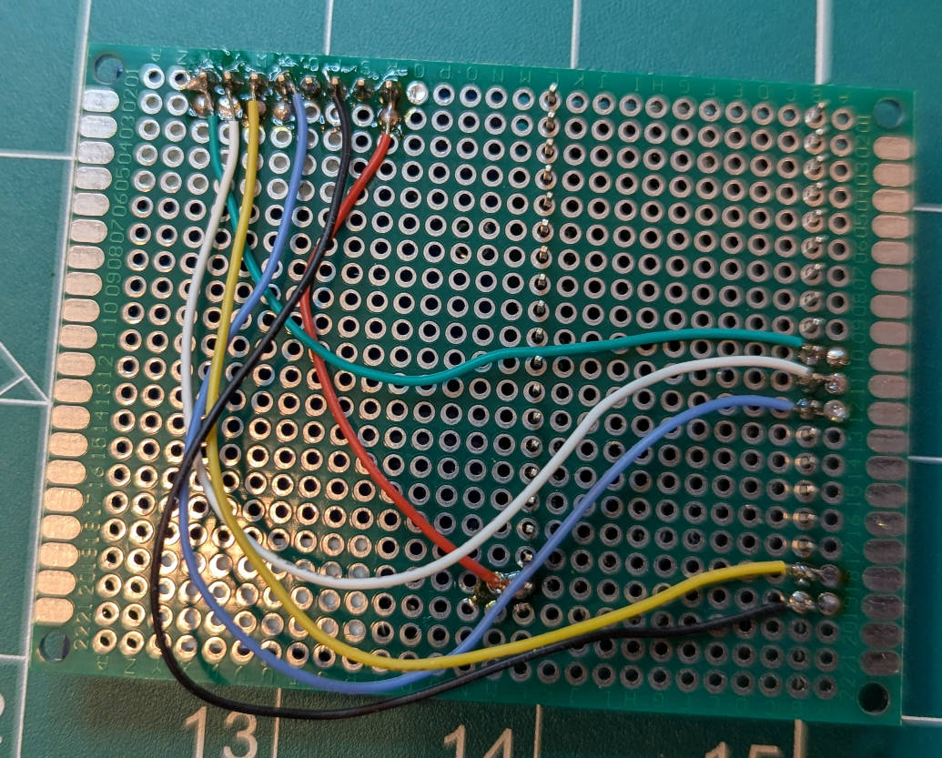
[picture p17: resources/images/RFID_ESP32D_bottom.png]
Bottom View of WriteRFID


**Table Of Contents**
* [Top](#writerfid-esp32d-hardware "Top")
* [Arduino IDE Board Selection](#arduino-ide-board-selection "Arduino IDE Board Selection")
* [Description](#description "Description")

## Arduino IDE Board Selection
[Top](#writerfid-esp32d-hardware "Top")<br>
I am using this board - the **32D** variant.
- https://www.aliexpress.com/item/3256806553795646.html

I think this board is based on the ESP32-WROOM-32D Devkit C.
- https://docs.espressif.com/projects/esp-idf/en/latest/esp32/hw-reference/esp32/get-started-devkitc.html

If using this board in the Arduino IDE, select the board as **"ESP32 Dev Module"**.

## Description
[Top](#writerfid-esp32d-hardware "Top")<br>
This routine writes and checks command info to PICC (RFID) cards.
It is intended to write PICC cards to be used by UniRemoteCYD.
- https://github.com/Mark-MDO47/UniRemote
- https://github.com/Mark-MDO47/UniRemote/tree/master/code/UniRemoteCYD

This routine runs on ESP32-WROOM-32D Devkit C using the Mifare RC522 RF IC Card Sensor Module.
- https://docs.espressif.com/projects/esp-dev-kits/en/latest/esp32/esp32-devkitc/user_guide.html
- https://docs.espressif.com/projects/esp-idf/en/latest/esp32/hw-reference/esp32/get-started-devkitc.html (ESP32-DevKitC V4)
- https://www.espressif.com/sites/default/files/documentation/esp32-wroom-32d_esp32-wroom-32u_datasheet_en.pdf

Exactly the same code is used on the UniRemoteCYD hardware and on this specialized ESP32D hardware.
- I got weary of re-programming the UniRemoteCYD back and forth and so I made this stand-alone programmer hardware.

The dialog with the operator is done using the serial port.

For details on the command format and how to run the code, see https://github.com/Mark-MDO47/UniRemote/edit/master/code/WriteRFID/README.md

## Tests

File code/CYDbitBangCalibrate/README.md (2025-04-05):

# CYDbitBangCalibrate

**Table Of Contents**
* [Top](#cydbitbangcalibrate "Top")
* [Arduino IDE Board Selection](#arduino-ide-board-selection "Arduino IDE Board Selection")
* [The Idea](#the-idea "The Idea")
* [Attributions](#attributions "Attributions")

## Arduino IDE Board Selection
* [Top](#cydbitbangcalibrate "Top")<br>
In the Arduino IDE, select the board as "ESP32 Dev Module". The CYD is based on the ESP32 D0WDQ6.

## The Idea
[Top](#cydbitbangcalibrate "Top")<br>
I am using the CYD pins that connect to the MicroSD slot for an SPI interface, but the CYD "normally" uses all four hardware SPI interfaces from the ESP32.
I wanted to free up an ESP32 hardware SPI channel so I adapted some code to use the XPT2046_Bitbang software-based SPI library for the touchscreen interface instead of the TFT_eSPI library.
This frees up the ESP32 VSPI hardware SPI channel for other uses.

This code is an adaptation of the Random Nerds touchscreen calibration routine that uses this XPT2046_Bitbang library.

## Attributions
[Top](#cydbitbangcalibrate "Top")<br>
The version of the software for CYD (ESP32-2432S028R or Cheap Yellow Display) screen touch calibration that I started from was
- Rui Santos & Sara Santos - Random Nerd Tutorials - https://RandomNerdTutorials.com/touchscreen-calibration/

The XPT2046_Bitbang library can be installed from the library manager (search for "XPT2046 Slim").
- https://github.com/TheNitek/XPT2046_Bitbang_Arduino_Library

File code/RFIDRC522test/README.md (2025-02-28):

# RFID RC522 test

**Table Of Contents**
* [Top](#rfid-rc522-test "Top")
* [Hardware](#hardware "Hardware")
* [Software](#software "Software")
  * [Multiple SPI Devices on Same SPI Bus](#multiple-spi-devices-on-same-spi-bus "Multiple SPI Devices on Same SPI Bus")
  * [All ESP32 Hardware SPI Ports Used Up - Need Software Bit Banging](#all-esp32-hardware-spi-ports-used-up-\--need-software-bit-banging "All ESP32 Hardware SPI Ports Used Up - Need Software Bit Banging")
    * [Touchscreen Calibration with XPT2046_Bitbang](#touchscreen-calibration-with-xpt2046_bitbang "Touchscreen Calibration with XPT2046_Bitbang")
    * [All Together Now](#all-together-now "All Together Now")
* [Documentation](#documentation "Documentation")
* [MicroSD Sniffer Cards](#microsd-sniffer-cards "MicroSD Sniffer Cards")
  * [SPI Sparkfun Sniffer Info](#spi-sparkfun-sniffer-info "SPI Sparkfun Sniffer Info")
  * [Blinken Labs Sniffer Info](#blinken-labs-sniffer-info "Blinken Labs Sniffer Info")

## Hardware
[Top](#rfid-rc522-test "Top")<br>
| Link | Description |
| --- | --- |
| https://www.amazon.com/dp/B07VLDSYRW | **READER/WRITER** HiLetgo 3pcs RFID Kit - Mifare RC522 RF IC Card Sensor Module + S50 Blank Card + Key Ring |
| https://www.amazon.com/dp/B07S63VT7X | **CARDS** Meikuler 13.56MHz MIFARE Classic 1K, RFID Smart Cards / M1 Cards, ISO14443A Printable Blank RFID PVC Cards |

- This RC522 RFID reader doesn't support I2C or UART without board modifications; just SPI
  - even though the IC itself supports I2C and UART, the board pins and strapping are just for SPI interface
  - look for Adrianotiger post #4 on Mar 2023 on https://forum.arduino.cc/t/esp32-rfid-rc522-i2c/1100200/3
  - here is webpage for the module including schematic https://www.sunrom.com/p/rfid-readerwriter-1356mhz-rc522-spi-module-with-cardkeychain
- On the other hand, the CYD board doesn't have enough unused GPIO pins coming out natively to use SPI
  - nominally requires 5 lines in addition to GND and 3.3V - see below for discussion of the "RESET" or "RST" line
  - the CYD MicroSD card reader uses SPI; a "sniffer" card can be used to access the GPIO lines from that

- RESET
  - Looking at the code for the "RFID_MFRC522v2 by Github Community" library, it appears that in 25 Jun 2020, v2.0.0 the library quit using the hardware reset pin and now uses only the software reset
  - You can still find the commented-out hardware reset code near Arduino/libraries/RFID_MFRC522v2/src/MFRC522v2.cpp line 81
  - In my experience this library works without connecting the hardware RST line
  - Thus the number of lines (and GPIO pins) needed is 4 in addition to GND and 3.3V

## Software
[Top](#rfid-rc522-test "Top")<br>
The original plan was to store the command string directly in the RFID card and have the RFID reader/writer on the CYD I2C bus along with the QR reader. See the [Hardware](#hardware "Hardware") section; this is not feasible.
Options:
- use MicroSD sniffer on the CYD and control both devices that way
  - https://www.sparkfun.com/sparkfun-microsd-sniffer.html
  - https://learn.sparkfun.com/tutorials/microsd-sniffer-hookup-guide/introduction
  - https://github.com/sparkfun/MicroSD_Sniffer.git
- have another ESP32 or 3.3V microcontroller that is on the I2C bus and use it to control the SPI bus to the RFID reader/writer.

Using the MicroSD sniffer on the CYD works.

### Multiple SPI Devices on Same SPI Bus
[Top](#rfid-rc522-test "Top")<br>
Some resources
- https://docs.arduino.cc/learn/communication/spi/
- https://forum.arduino.cc/t/multiple-spi-chip-select-question/101140
- https://forum.arduino.cc/t/how-to-use-spi-for-multiple-devices/427739

It turns out that the MicroSD card and the Touchscreen are not set up for this purpose.
- To use this technique they would need to share all the GPIO SPI pins except for SPI Chip Select (CS).
- These two SPI interfaces on the CYD share no GPIO pins.

Because of this we need to use software bit banging for one SPI port to free up the hardware SPI port for use on the MicroSD card. It is common to use the software bit banging for interfacing with the touch screen since it has a low amount of actual data to transfer and the software SPI interface is slower than the hardware SPI interface.

### All ESP32 Hardware SPI Ports Used Up - Need Software Bit Banging
[Top](#rfid-rc522-test "Top")<br>
This general Arduino usage doc for LVGL says "To get started it's recommended to use TFT_eSPI library as a TFT driver to simplify testing."
- https://docs.lvgl.io/master/details/integration/framework/arduino.html

However, in the case of the Cheap Yellow Display, there are not enough available hardware SPI resources on the ESP32 to handle the display (HSPI), the touchscreen (VSPI), and the MicroSD card slot (out of luck) at the same time (along with the other HW SPI ports used for general purpose stuff like FLASH memory).
  - https://github.com/witnessmenow/ESP32-Cheap-Yellow-Display
  - Using bit-banging so touch and SD can work in same program - https://github.com/witnessmenow/ESP32-Cheap-Yellow-Display/blob/main/TROUBLESHOOTING.md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

For that reason I am using the XPT2046_Bitbang library instead of the TFT_eSPI library for the touchscreen. This seems to work OK with some changes to the code.
- This library can be installed from the Arduino IDE library manager (Search for "XPT2046 Slim")

#### Touchscreen Calibration with XPT2046_Bitbang
[Top](#rfid-rc522-test "Top")<br>
I made a version of the Random Nerd CYDCalibrate.ino
- Rui Santos & Sara Santos - Random Nerd Tutorials - https://RandomNerdTutorials.com/touchscreen-calibration/

... that I call  CYDbitBangCalibrate.ino here:
- https://github.com/Mark-MDO47/UniRemote/tree/master/code/CYDbitBangCalibrate

This is a good way to see how to change from CYD touchscreen operation using the XPT2046_Bitbang library instead of the TFT_eSPI library: compare the code from the following two sources
- TFT_eSPI - https://RandomNerdTutorials.com/touchscreen-calibration/
- XPT2046_Bitbang - https://github.com/Mark-MDO47/UniRemote/tree/master/code/CYDbitBangCalibrate

For some reason I don't understand, the calibration constants generated are fairly different between the two calibration routines using different SPI libraries.

If you use the XPT2046_Bitbang library and want to calibrate the touchscreen, you might want to use something similar to my CYDbitBangCalibrate program to generate the calibration constants.

#### All Together Now
[Top](#rfid-rc522-test "Top")<br>
https://github.com/Mark-MDO47/UniRemote/tree/master/code/UniRemoteCYD contains a program that uses
- lvgl library
- XPT2046_Bitbang library
- MicroSD Sniffer and HW VSPI for RC522 RF IC Card Sensor Module
- I2C for QR Code reader

At this time that is still a work in progress, but it does operate all the devices.

I used my CYDbitBangCalibrate calibration constants in the cyd_input_read() routine found in https://github.com/Mark-MDO47/UniRemote/tree/master/code/UniRemoteCYD/cyd_input_read.h<br>
I will probably rework this UniRemoteCYD program further but I don't expect to change the routine name cyd_input_read so you should be able to find it.

## Documentation
[Top](#rfid-rc522-test "Top")<br>
Documentation of the MIFARE Classic 1K card
- https://www.nxp.com/docs/en/data-sheet/MF1S50YYX_V1.pdf

Documentation of the MFRC522v2 library
- https://osslibraries.github.io/Arduino_MFRC522v2/

I used the Random Nerd tutorials to get up to speed.
- https://randomnerdtutorials.com/esp32-spi-communication-arduino/
- https://randomnerdtutorials.com/esp32-i2c-communication-arduino-ide/
- https://randomnerdtutorials.com/esp32-i2c-master-slave-arduino/
- https://randomnerdtutorials.com/esp32-spi-communication-arduino/
- https://randomnerdtutorials.com/esp32-mfrc522-rfid-reader-arduino/

More documentation on the CYD internal pinouts and the connector types.
- https://debugdiaries.co.uk/esp32-cheap-display-cyd-pinouts/ - compact, useful format
- https://macsbug.wordpress.com/2022/08/17/esp32-2432s028/ - need to Google-translate from Japanese but quite good

## MicroSD Sniffer Cards
[Top](#rfid-rc522-test "Top")<br>
I am using the Arduino library RFID_MFRC522v2 by GithubCommunity. An important point when using this library in the CYD is that the reset pin RST (ESP32 pin 21) is unused since 25 Jun 2020 v2.0.0. That is fortunate, since in the CYD pin 21 is used for other purposes. I tried an experiment leaving it floating and that seemed to work.

### SPI Sparkfun Sniffer Info
[Top](#rfid-rc522-test "Top")<br>
The Sparkfun MicroSD card sniffer carried all the signals needed for using the RC522 RFID card reader.
- https://www.sparkfun.com/sparkfun-microsd-sniffer.html

GPIO channels for Sparkfun MicroSD card sniffer on the CYD are shown below.
- NOTE: "-" (single dash) means No Connect. Had to do this since on Blinken Labs JTAG sniffer with Treedix JTAG breakout board NC is used as a label.

| Sparkfun | Alt | ESP32 GPIO pin | RC522 | Color | Comment |
| --- | --- | --- | --- | --- | --- |
| DAT2 |  |  |  | - | unused |
| CD | CS | 5 | SDA | Green | TF_CS |
| CMD | MOSI | 23 | MOSI | Yellow |  |
| GND | GND |  | GND | Black | ground |
| VCC | VDD |  | 3.3V | Red | 3.3V |
| CLK | CLX | 18 | SCK | White | TF_CLK |
| DAT0 | MISO | 19 | MISO | Blue |  |
| DAT1 |  |  |  | - | unused |
|  |  | 21 | RST | - | unused |
|  |  |  | IRQ | - | unused |

### Blinken Labs Sniffer Info
[Top](#rfid-rc522-test "Top")<br>
The Blinken Labs MicroSD to JTAG adapter for ESP32 carries most of the signals needed for using the RC522 RFID card reader. This card was not designed as a general purpose MicroSD sniffer but rather as a JTAG interface; it has all the signals needed for the JTAG interface.
- https://shop.blinkinlabs.com/products/microsd-to-jtag-adapter-for-esp32

I connected the Blinken Labs board via JTAG cable to a Treedix JTAG breakout card.
- https://www.amazon.com/dp/B09DKDG7XN

As before, "-" (single dash) means No Connect.

| BLINKIN | Brkt-Bd | Alt | ESP32 GPIO pin | RC522 | Color  | Comment |
| --- | --- | --- | --- | --- | --- | --- |
| DATA2/TDI | NC | - | - |  | unused |
| DATA3/TCK | CLK | CS | 5 | SDA | Green | TF_CS |
| CMD/TD0 | SW0 | MOSI | 23 | MOSI | Yellow |  |
| 3.3V-jumper | VCC | 3.3V | 3.3V | 3.3V | Red | 3.3V |
| CLK/TMS | SWIO | CLX | 18 | SCK | White | TF_CLK |
| GND | GNDd | GND | GND | GND | Black | ground |
| DATA3 | - | - | - | - |  | 19 MISO - not wired |
| DATA2 | - | - | - |  |  | unused |
| GND | GND(1) | GND | GND | GND |  | connected internally |
| GND | GND(2) | GND | GND | GND |  | connected internally |
| - | /RST | - | - | - |  | unused |
| - | KEY | - | - | - |  | unused |

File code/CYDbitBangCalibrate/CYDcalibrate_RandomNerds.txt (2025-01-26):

USE THE FOLLOWING COEFFICIENT VALUES TO CALIBRATE YOUR TOUCHSCREEN
Computed X:  alpha_x = 0.001, beta_x = 0.092, delta_x = -38.259
Computed Y:  alpha_y = 0.067, beta_y = -0.001, delta_y = -18.374

    alpha_x = 0.001;
    beta_x = 0.092;
    delta_x = -38.259;
    alpha_y = 0.067;
    beta_y = -0.001;
    delta_y = -18.374;

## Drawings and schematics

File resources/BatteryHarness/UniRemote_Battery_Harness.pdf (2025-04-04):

# Charger

## JST

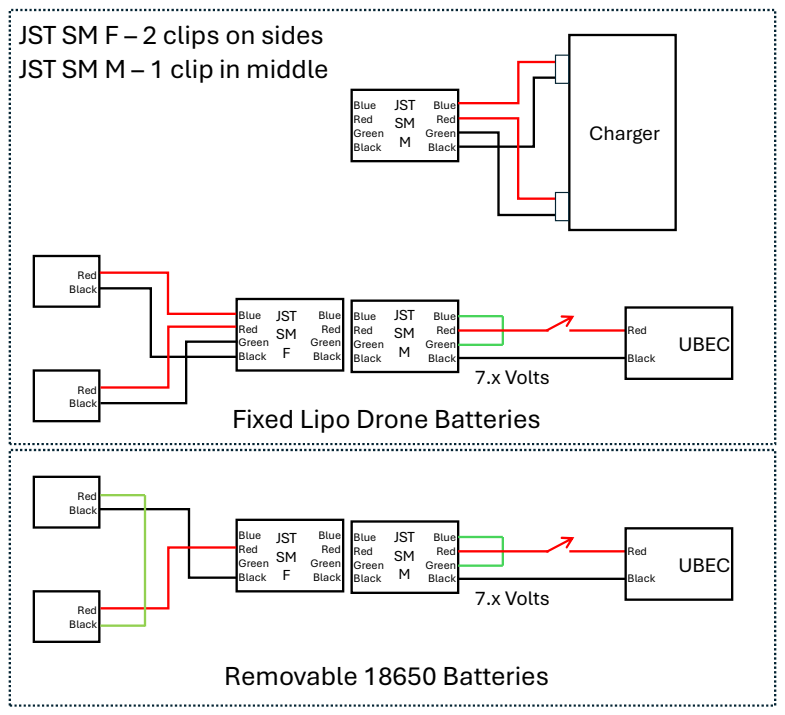
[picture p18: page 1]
Blue Red Green Black; Blue Red; Red Black; 7.x Volts; Red; Black; UBEC; Removable 18650 Batteries; JST SM F; JST SM M

JST SM F – 2 clips on sides
JST SM M – 1 clip in middle

Green
Black
Fixed Lipo Drone Batteries

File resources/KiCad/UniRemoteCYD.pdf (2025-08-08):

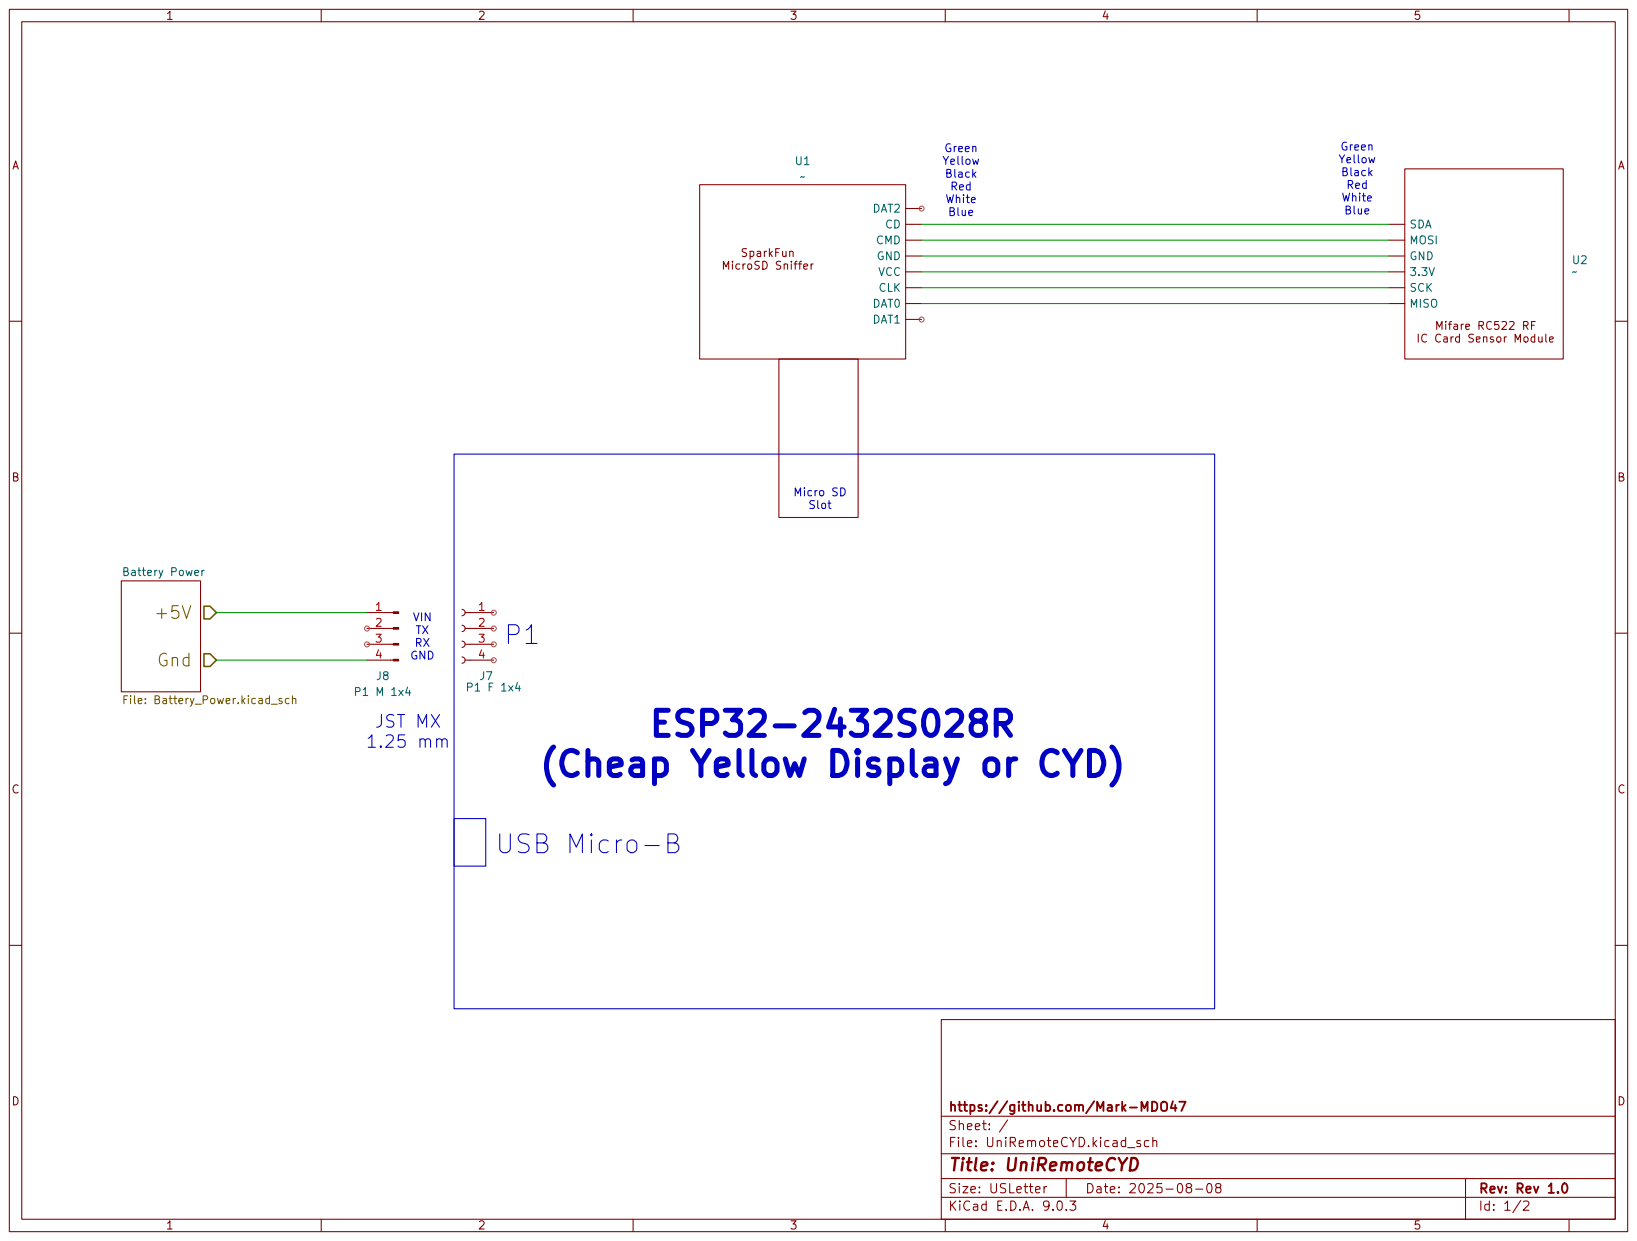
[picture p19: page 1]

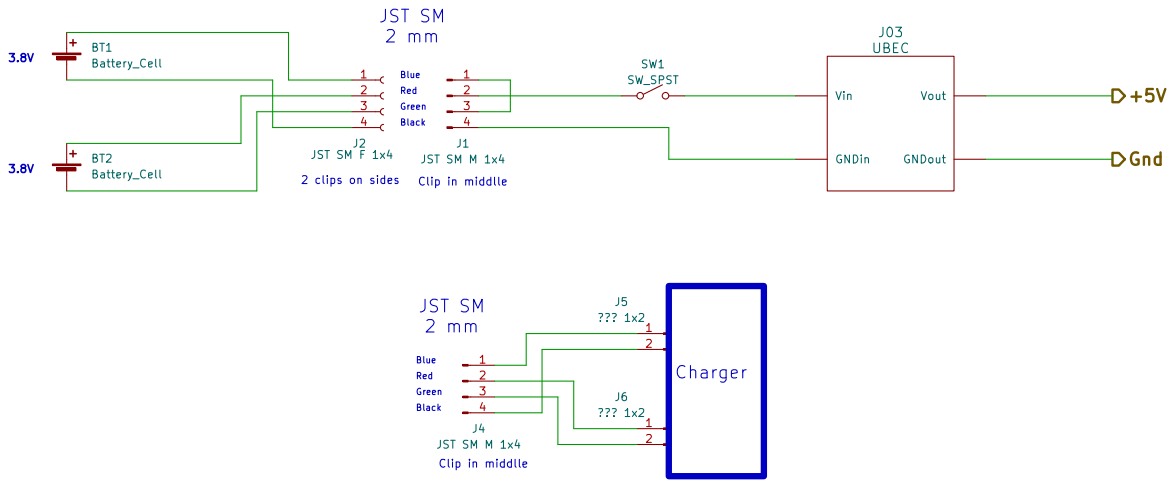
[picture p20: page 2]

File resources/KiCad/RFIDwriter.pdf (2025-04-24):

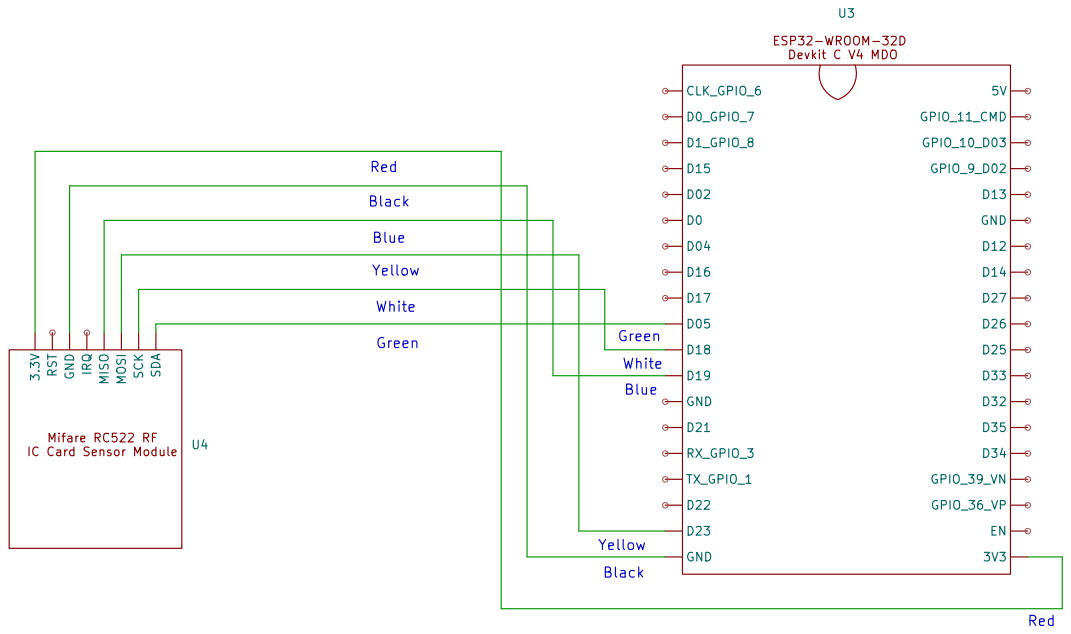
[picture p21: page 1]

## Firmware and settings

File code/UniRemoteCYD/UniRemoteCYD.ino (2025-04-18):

/* Author: https://github.com/Mark-MDO47  Dec. 21, 2024
 *  https://github.com/Mark-MDO47/UniRemote
 *  
 *  This code will scan a command (QR code or RFID or ??) and send it to
 *     the appropriate MAC address using ESP-NOW point-to-point on WiFi.
 *  The command is sent in plain text, not encrypted.
 *
 * ESP-NOW is a protocol designed by Espressif Systems https://www.espressif.com/
 *     This UniRemote code expects to run on particular hardware as described below.
 *     The receiver(s) of the command(s) can be based on just about any ESP32 that includes WiFi.
 *
 * UniRemote runs on the "Cheap Yellow Display" ESP32-2432S028R based on ESP32-D0WDQ6.
 *     I used this one: https://www.aliexpress.us/item/3256805697430313.html
 *
 * The QR code reader used is the Tiny Code Reader from Useful Sensors
 *     I used this one: https://www.sparkfun.com/products/23352
 *     See https://github.com/usefulsensors/tiny_code_reader_arduino.git
 *
 * The RFID reader used is (as far as I can tell) pretty common.
 *     I used this one: https://www.amazon.com/dp/B07VLDSYRW
 *     It is capable of reading and/or writing RFID Smart Cards.
 *     The controller chip could support UART or I2C or SPI interfaces,
 *        but the only interface supported without board modification is the
 *        SPI interface. Since the CYD didn't have enough pins available without board
 *        modification, I am using a "sniffer" that takes the signals from the CYD MicroSD slot.
 *     I used this sniffer: https://www.sparkfun.com/sparkfun-microsd-sniffer.html
 *        See also https://learn.sparkfun.com/tutorials/microsd-sniffer-hookup-guide/introduction
 *     I used these RFID Smart Cards ISO14443A: https://www.amazon.com/dp/B07S63VT7X
 *
 * The scanned command contains the MAC address and the command string. This code will
 *     dynamically register the MAC addresses but ESP_NOW has a limit of 20 MAC
 *     addresses that can be registered at once.
 *   
 *  The scanned command should be a text tab-separated-variable text file of the following form:
 *  <MAC ADDRESS><"|"><COMMAND STRING><TAB><DESCRIPTION STRING>
 *  
 *  <MAC ADDRESS> is a string of the following exact form:
 *      ##:##:##:##:##:##
 *    This is the MAC Address that will be used to send the ESP-NOW message;
 *      the MAC address of the target system.
 *    Note that this is a six-part MAC address in hexadecimal. Each hex number
 *    is exactly two digits long. If you need to start it with a zero, do so.
 *    Because I am a lazy coder, formatting the string properly is up to you.
 *  
 *  <COMMAND STRING> is a short (maximum 249 characters + zero termination) command
 *    The receiving MAC address will receive it as a zero-terminated string (including
 *    the zero terminator).
 *
 * <DESCRIPTION STRING> can be zero length or more, but for consistency
 *    the <TAB> prior to the description string is required.
 *    The description is just for your purposes; it is not sent to the ESP-NOW target.
 *
 * <"|"> is the single character of a vertical bar (the bash pipe character).
 *
 * <TAB> is the single character Tab (ASCII Horizontal Tab, '\t', hex 0x09)
 *
 * QRcode.py in https://github.com/Mark-MDO47/MDOpythonUtils
 *    will create such a QR code from text input. It requires that you
 *    install the "qrcode" package, using conda or pip or whatever.
 *    I use the command line "python QRcode.py -s intructions.txt"
 *    Each QR code is generated with a short *.html to allow printing.
 *
 * Future plans - perhaps include voice commands and a few buttons.
 */

/*
   Copyright 2024, 2025 Mark Olson

   Licensed under the Apache License, Version 2.0 (the "License");
   you may not use this file except in compliance with the License.
   You may obtain a copy of the License at

       http://www.apache.org/licenses/LICENSE-2.0

   Unless required by applicable law or agreed to in writing, software
   distributed under the License is distributed on an "AS IS" BASIS,
   WITHOUT WARRANTIES OR CONDITIONS OF ANY KIND, either express or implied.
   See the License for the specific language governing permissions and
   limitations under the License.
 */

 // This code was developed after reading the Random Nerd Tutorials below.
 // There are significant differences in this code and the tutorials, but I want to give a
 //    tip of the hat to Rui Santos & Sara Santos for the wonderful work they do.
 // Below is the attribution from the Random Nerd Tutorial on ESP-NOW.
 /*
  Rui Santos & Sara Santos - Random Nerd Tutorials
  Complete project details at https://RandomNerdTutorials.com/esp-now-esp32-arduino-ide/
  Permission is hereby granted, free of charge, to any person obtaining a copy of this software and associated documentation files.
  The above copyright notice and this permission notice shall be included in all copies or substantial portions of the Software.
*/
// Below is the attribution from the Random Nerd Tutorial on LVGL.
/*  Rui Santos & Sara Santos - Random Nerd Tutorials - https://RandomNerdTutorials.com/esp32-lvgl-ebook/
    THIS EXAMPLE WAS TESTED WITH THE FOLLOWING HARDWARE:
    1) ESP32-2432S028R 2.8 inch 240×320 also known as the Cheap Yellow Display (CYD): https://makeradvisor.com/tools/cyd-cheap-yellow-display-esp32-2432s028r/
      SET UP INSTRUCTIONS: https://RandomNerdTutorials.com/cyd-lvgl/
    2) REGULAR ESP32 Dev Board + 2.8 inch 240x320 TFT Display: https://makeradvisor.com/tools/2-8-inch-ili9341-tft-240x320/ and https://makeradvisor.com/tools/esp32-dev-board-wi-fi-bluetooth/
      SET UP INSTRUCTIONS: https://RandomNerdTutorials.com/esp32-tft-lvgl/
    Permission is hereby granted, free of charge, to any person obtaining a copy of this software and associated documentation files.
    The above copyright notice and this permission notice shall be included in all copies or substantial portions of the Software.
*/

// Also a giant tip of the hat to the folks at LVGL
//   https://lvgl.io/
//   https://github.com/lvgl/lvgl/tree/master
//   https://docs.lvgl.io/master/examples.html

// and this info on using I2C and SPI with the "Cheap Yellow Display" ESP32-2432S028R GPIO pins
//   https://github.com/witnessmenow/ESP32-Cheap-Yellow-Display/discussions/3
//   https://github.com/witnessmenow/ESP32-Cheap-Yellow-Display/blob/main/ADDONS.md#wiring
//   https://github.com/witnessmenow/ESP32-Cheap-Yellow-Display/blob/155f70e485994c9423c3af1035bb5ce72899ff01/Examples/InputTests/NunchuckTest/NunchuckTest.ino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

// Below is the attribution from the Random Nerd Tutorial on ESP32 with MFRC522 RFID Reader/Writer (Arduino IDE).
/*
  Rui Santos & Sara Santos - Random Nerd Tutorials
  Complete project details at https://RandomNerdTutorials.com/esp32-mfrc522-rfid-reader-arduino/
  Permission is hereby granted, free of charge, to any person obtaining a copy of this software and associated documentation files.  
  The above copyright notice and this permission notice shall be included in all copies or substantial portions of the Software.
*/

// Also a giant tip of the hat to the folks at https://github.com/witnessmenow/ESP32-Cheap-Yellow-Display
//    and https://github.com/TheNitek/XPT2046_Bitbang_Arduino_Library and
//    for pioneering the method of using
//    "bit banging" (software-controlled) SPI on the touchscreen and freeing up the hardware VSPI channel
//    for use on the RC522-based RFID reader/writer via the MicroSD Sniffer. See 
//    https://github.com/witnessmenow/ESP32-Cheap-Yellow-Display/blob/main/TROUBLESHOOTING.md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

// ----------------------------
// Standard Libraries
// ----------------------------

#include <SPI.h>

// ----------------------------
// Additional Libraries - each one of these will need to be installed.
// ----------------------------

/*  Install the "lvgl" library version 9.2 by kisvegabor to interface with the TFT Display - https://lvgl.io/
    *** IMPORTANT: lv_conf.h available on the internet will probably NOT work with the examples available at Random Nerd Tutorials ***
    *** YOU MUST USE THE lv_conf.h FILE PROVIDED IN THE LINK BELOW IN ORDER TO USE THE EXAMPLES FROM RANDOM NERD TUTORIALS ***
    FULL INSTRUCTIONS AVAILABLE ON HOW CONFIGURE THE LIBRARY: https://RandomNerdTutorials.com/cyd-lvgl/ or https://RandomNerdTutorials.com/esp32-tft-lvgl/   */
// https://github.com/lvgl/lvgl.git
#include <lvgl.h>

// NOTE WE ARE USING XPT2046_Bitbang INSTEAD OF TFT_eSPI
// A library for interfacing with the touch screen "bit banging" (software-controlled) SPI
// Can be installed from the library manager (Search for "XPT2046 Slim")
// https://github.com/TheNitek/XPT2046_Bitbang_Arduino_Library
#include <XPT2046_Bitbang.h>

// NOTE WE ARE USING XPT2046_Bitbang INSTEAD OF TFT_eSPI
// A library for interfacing with LCD displays
// Can be installed from the library manager (Search for "TFT_eSPI")
// https://github.com/Bodmer/TFT_eSPI
// #include <TFT_eSPI.h>
// NOTE WE ARE USING XPT2046_Bitbang INSTEAD OF TFT_eSPI

#define INCLUDE_RFID_SENSOR 1  // set to 1 to include RFID Sensor scan for commands
#define INCLUDE_QR_SENSOR   0  // set to 1 to include QR Code Reader scan for commands

#if INCLUDE_RFID_SENSOR
// A library for interfacing with the RC522-based RFID reader either via I2C or SPI
// Can be installed from the library manager (Search for "MFRC522v2" by GithubCommunity)
// https://github.com/OSSLibraries/Arduino_MFRC522v2
#include <MFRC522v2.h>
#include <MFRC522DriverSPI.h>
#include <MFRC522DriverPinSimple.h>
#include <MFRC522Debug.h>

// Learn more about using SPI/I2C or check the pin assigment for your board: https://github.com/OSSLibraries/Arduino_MFRC522v2#pin-layout
//   basically we are using the ESP32 VSPI pins; see https://github.com/Mark-MDO47/UniRemote/blob/master/code/RFIDRC522test/README.md#spi-sniffer-info
MFRC522DriverPinSimple ss_pin(5);

MFRC522DriverSPI driver{ss_pin}; // Create SPI driver
MFRC522 mfrc522{driver};         // Create MFRC522 instance

MFRC522::MIFARE_Key key;
#endif // INCLUDE_RFID_SENSOR

#include <esp_now.h>   // for ESP-NOW
#include <WiFi.h>      // for ESP-NOW
#include "../wifi_key.h"  // WiFi secrets


#if INCLUDE_QR_SENSOR
  #include <Wire.h>     // for QR sensor (Tiny Code Reader) and anything else
  #include "../tiny_code_reader/tiny_code_reader.h" // see https://github.com/usefulsensors/tiny_code_reader_arduino.git
#endif // INCLUDE_QR_SENSOR

// Install the "XPT2046_Touchscreen" library by Paul Stoffregen to use the Touchscreen - https://github.com/PaulStoffregen/XPT2046_Touchscreen - Note: this library doesn't require further configuration
//   NOTE: this works together with the XPT2046_Bitbang library we are using
#include <XPT2046_Touchscreen.h>

// DEBUG definitions
#define DBG_SERIALPRINT Serial.print
#define DBG_SERIALPRINTLN Serial.println
#define DEBUG_PRINT_TOUCHSCREEN_INFO 0    // Print Touchscreen info about X, Y and Pressure (Z) on the Serial Monitor
#define DEBUG_PRINT_PICC_INFO 1           // Print UID and other info when PICC RFID card detection on the Serial Monitor
#define DEBUG_PRINT_PICC_DATA_FINAL 1     // Print the data we read in ASCII after all reads
#define DEBUG_PRINT_PICC_DATA_EACH  0     // Print the data we read in ASCII after each read

#if INCLUDE_RFID_SENSOR
// PICC definitions for RFID reader
#define PICC_EV1_1K_NUM_SECTORS         16 // 16 sectors each with 4 blocks of 16 bytes
#define PICC_EV1_1K_SECTOR_NUM_BLOCKS   4  // each sector has 4 blocks of 16 bytes
#define PICC_EV1_1K_BLOCK_NUM_BYTES     16 // each block has 16 bytes
#define PICC_EV1_1K_BLOCK_SECTOR_AVOID  3  // avoid blockAddress 0 and block 3 within each sector
#define PICC_EV1_1K_START_BLOCKADDR     1  // do not use blockAddress 0
#define PICC_EV1_1K_END_BLOCKADDR ((PICC_EV1_1K_SECTOR_NUM_BLOCKS) * PICC_EV1_1K_NUM_SECTORS - 1)
#endif // INCLUDE_RFID_SENSOR

// PIN definitions

// Connector P1 - 
// Connector P3 - GND,35,22,21 (note 21 is shared, don't mess with it)

// Connector CN1 - GND,22,27,3V3
// these definitions have the QR code reader wire colors matching the CYD wire colors
//    yellow = SCL
//    blue   = SDA
#define CYD_CN1_SDA 22 // for "Cheap Yellow Display" ESP32-2432S028R
#define CYD_CN1_SCL 27 // for "Cheap Yellow Display" ESP32-2432S028R

// internal CYD RGB LED Pins
#define CYD_LED_RED    4
#define CYD_LED_GREEN 16
#define CYD_LED_BLUE  17
#define CYD_LED_ON  LOW  // inverted
#define CYD_LED_OFF HIGH // inverted

// Touchscreen pins
#define XPT2046_IRQ 36   // T_IRQ
#define XPT2046_MOSI 32  // T_DIN
#define XPT2046_MISO 39  // T_OUT
#define XPT2046_CLK 25   // T_CLK
#define XPT2046_CS 33    // T_CS

// define touchscreen and LVGL definitions

// NOTE: setting this to 1 seems to cause problems with LVGL timeouts
#define USE_LV_TICK_SET_CB 0 // 1 to use lv_tick_set_cb() in setup; 0 to use lv_tick_inc() in loop

// NOTE WE ARE USING XPT2046_Bitbang INSTEAD OF TFT_eSPI
      // SPIClass touchscreenSPI = SPIClass(VSPI);
XPT2046_Bitbang ts(XPT2046_MOSI, XPT2046_MISO, XPT2046_CLK, XPT2046_CS); // create software-controlled SPI for touchscreen
// TFT_eSPI tft = TFT_eSPI();
// NOTE WE ARE USING XPT2046_Bitbang INSTEAD OF TFT_eSPI
XPT2046_Touchscreen touchscreen(XPT2046_CS, XPT2046_IRQ);


#define SCREEN_WIDTH 240
#define SCREEN_HEIGHT 320
#define SCREEN_LSCAPE_WIDTH  SCREEN_HEIGHT
#define SCREEN_LSCAPE_HEIGHT SCREEN_WIDTH

// Touchscreen coordinates: (x, y) and pressure (z)
int x, y, z;

#define DRAW_BUF_SIZE (SCREEN_WIDTH * SCREEN_HEIGHT / 10 * (LV_COLOR_DEPTH / 8))
uint32_t draw_buf[DRAW_BUF_SIZE / 4];

// coloration
lv_style_t g_style_blue, g_style_yellow, g_style_red, g_style_green, g_style_grey, g_style_ghost;

// size
lv_style_t g_style_screen_width_btn_height;
lv_style_t g_style_screen_width_comm_height;

const int32_t CYDsampleDelayMsec = 5;

// ESP-NOW definitions
static uint8_t g_rcvr_mac_addr[ESP_NOW_ETH_ALEN * ESP_NOW_MAX_TOTAL_PEER_NUM];
static uint8_t g_rcvr_peer_num = 0; // count how many peers we put into our table (20 max)
static uint8_t g_last_scanned_cmd_count = 0; // count how many we scan and possibly process

esp_now_peer_info_t rcvr_peer_info; // will be filled in later

typedef int32_t uni_esp_now_status_t;
#define UNI_ESP_NOW_CB_NEVER_HAPPENED -1 // my own status
static uni_esp_now_status_t g_last_send_callback_status = UNI_ESP_NOW_CB_NEVER_HAPPENED; // -1 means never happened
static uint16_t g_msg_last_esp_now_rebuild_msg_cb = 0;    // nonzero when need to rebuild status message
static uint16_t g_msg_last_esp_now_display_status_cb = 0; // nonzero when need to display status message on screen
static uint16_t g_msg_last_esp_now_reset_esp_now = 0;     // nonzero when need to completely reset esp-now
static char g_msg_last_esp_now_result_status[1024];
static char g_msg_last_opr_comm_status[1024];
static char g_msg_prev_opr_comm_status[1024];
static char g_cmd_in_proc_or_prev[ESP_NOW_MAX_DATA_LEN+1];

#define UNI_CMD_QNUM_NOW    0 // 0==sending now, 1==next up
#define UNI_CMD_QNUM_NEXT   1 // 0==sending now, 1==next up
#define UNI_CMD_QNUM_NUM    2 // 0==sending now, 1==next up
typedef struct {
  char scanned_cmd[ESP_NOW_MAX_DATA_LEN+2];
  uint16_t scanned_cmd_len;
} uni_cmd_queue_t;
static uni_cmd_queue_t g_cmd_queue[UNI_CMD_QNUM_NUM]; // queue for msgs; 0==sending now, 1==next up

// UNI REMOTE definitions
#define UNI_ESP_NOW_MSEC_PER_MSG_MIN 500 // minimum millisec between sending messages

#define UNI_STATE_WAIT_CMD     0    // last cmd all done, wait for next cmd (any source OK)
#define UNI_STATE_CMD_SEEN     1    // command in queue, waiting for GO or CLEAR
#define UNI_STATE_SENDING_CMD  2    // command being sent (very short state)
#define UNI_STATE_WAIT_CB      3    // waiting for send callback (very short state)
#define UNI_STATE_SHOW_STAT    4    // show error status and allow abort
#define UNI_STATE_NUM          5    // number of states
uint8_t g_uni_state = UNI_STATE_WAIT_CMD;

#define UNI_STATE_NO_ERROR 0  // this UNI_STATE is in error
#define UNI_STATE_IN_ERROR 1  // this UNI_STATE is in error
uint8_t g_uni_state_error = UNI_STATE_NO_ERROR;

// some error codes that can be displayed just as if ESP_ERR_ESPNOW_ code
#define UNI_ERR_TOO_SOON        501 // too soon to send another ESP-NOW message
#define UNI_ERR_CMD_DECODE_FAIL 502 // could not decode MAC from CMD

uint32_t g_uni_state_times[UNI_STATE_NUM];

uint8_t g_change_send_no_view = 1;  // 1==send command immediately, 0==view command before sending

uint16_t g_cmd_scanned_by = 0;      // see below for definitions
#define UNI_CMD_SCANNED_BY_NONE 0
#define UNI_CMD_SCANNED_BY_QR   1
#define UNI_CMD_SCANNED_BY_PICC 2


#define ACTION_BUTTON_LEFT  0   // left top
#define ACTION_BUTTON_MID   1   // middle top
#define ACTION_BUTTON_RIGHT 2   // right top
#define ACTION_BUTTON_NUM 3     // number of action buttons at top of screen
typedef struct {
  lv_obj_t * button;            // object pointer for button itself
  lv_obj_t * button_label;      // for text on the button
  lv_obj_t * button_text_label; // object pointer for external button text
  uint16_t btn_idx;             // index to the action button
} action_button_t;
action_button_t g_action_buttons[ACTION_BUTTON_NUM]; // for three buttons on top screen

typedef struct {
  uint8_t  pressed;             // non-zero for new button press
  uint8_t  btn_idx;             // index to the action button
  uint8_t  uni_state;           // g_uni_state at time of button press
  uint8_t  uni_state_error;     // g_uni_state_error at time of button press
} button_press_t;
button_press_t g_button_press;

typedef struct {
  lv_obj_t * label_obj;
  lv_obj_t * label_text;
} styled_label_t;
styled_label_t g_styled_label_last_status; // 2 lines storage for last error on bottom screen
styled_label_t g_styled_label_opr_comm;    // 5 lines storage for opr communication in middle screen

char g_msg[1025]; // for generating text strings

/////////////////////////////////////////////////////////////////////////////////////////////////////////
// uni_lv_button_text_style - set button texts and style
//    p_btn_idx - within g_action_buttons[]
//    p_label   - label within button
//    p_text    - text under button
//    p_style   - button style to use
//    
void uni_lv_button_text_style(uint8_t p_btn_idx, const char * p_label, const char * p_text, lv_style_t * p_style) {
  lv_obj_add_style(g_action_buttons[p_btn_idx].button, p_style, 0);
  lv_label_set_text(g_action_buttons[p_btn_idx].button_label, p_label);
  lv_label_set_text(g_action_buttons[p_btn_idx].button_text_label, p_text);
} // end uni_lv_button_text_style()

/////////////////////////////////////////////////////////////////////////////////////////////////////////
// uni_lv_last_status_text_style - set last_status texts and style
//    p_text    - text for last status
//
// uses g_style_green if no FAIL found in p_text
// else g_style_yellow
//    
void uni_lv_last_status_text_style(char * p_text) {
    if (NULL == strstr(p_text,"FAIL"))
      lv_obj_add_style(g_styled_label_last_status.label_obj, &g_style_green, 0);
    else
      lv_obj_add_style(g_styled_label_last_status.label_obj, &g_style_yellow, 0);
    lv_label_set_text(g_styled_label_last_status.label_text, p_text);
} // end uni_lv_last_status_text_style()
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
void loop() {
  uint32_t msec_now = millis();
  esp_err_t send_status;

  if (0 != g_button_press.pressed) { handle_button_press(); }
  else switch (g_uni_state) {
    case UNI_STATE_WAIT_CMD:    // last cmd all done, wait for next cmd
      uni_do_esp_now_callback_status(); // if there is callback status, show it
      if (0 == uni_get_command(msec_now)) {
        sprintf(g_msg,"No scanned command found, waiting...\n  %s", g_msg_last_esp_now_result_status);
        uni_lv_last_status_text_style(g_msg);
      }
      break;
    case UNI_STATE_CMD_SEEN:   // command in queue, waiting for GO or CLEAR
      break;
    case UNI_STATE_SENDING_CMD: // command being sent (very short state)
      send_status = uni_esp_now_cmd_send();
      if (send_status == ESP_OK) {
        sprintf(g_msg_last_opr_comm_status, "\nESP-NOW send success CMD #%d ", g_last_scanned_cmd_count);
        sprintf(g_msg_last_esp_now_result_status, "ESP-NOW send success CMD #%d %s", g_last_scanned_cmd_count, g_cmd_queue[UNI_CMD_QNUM_NOW].scanned_cmd);
        uni_lv_last_status_text_style(g_msg_last_esp_now_result_status);
        g_uni_state = UNI_STATE_WAIT_CB;
        DBG_SERIALPRINTLN("Change state to UNI_STATE_WAIT_CB");
      }
      else {
        sprintf(g_msg_last_opr_comm_status, "\nESP-NOW send ERROR CMD #%d ", g_last_scanned_cmd_count);
        sprintf(g_msg_last_esp_now_result_status, "ESP-NOW ERROR: sending CMD #%d: %s\n  %s", g_last_scanned_cmd_count, g_cmd_queue[UNI_CMD_QNUM_NOW].scanned_cmd, uni_esp_now_decode_error(send_status));
        uni_lv_last_status_text_style(g_msg_last_esp_now_result_status); // yellow if "FAIL"
        if (0 != g_change_send_no_view)
          g_uni_state = UNI_STATE_WAIT_CMD;  // show error status and scan next cmd
        else
          g_uni_state = UNI_STATE_SHOW_STAT; // show error status and allow abort
      }
      break;
    case UNI_STATE_WAIT_CB:     // waiting for send callback
      break;
    case UNI_STATE_SHOW_STAT:   // show error status and allow abort
      uni_do_esp_now_callback_status(); // if there is callback status, show it
      break;
    default:
      // FIXME TODO should never get here
      break;
  }
  uni_display_state();

  lv_task_handler();  // let the GUI do its work

#if (1-USE_LV_TICK_SET_CB) // if not using lv_tick_set_cb()
  // not using lv_tick_set_cb(); do with manual estimate
  lv_tick_inc(CYDsampleDelayMsec); // tell LVGL how much time has passed
#endif // (USE_LV_TICK_SET_CB) end if not using lv_tick_set_cb(); otherwise lv_tick_set_cb() done in setup() after lv_init()
  delay(CYDsampleDelayMsec);
} // end loop()

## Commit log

2024-12-23 UniRemote.ino now sends msg skipping the MAC address
    [UniRemote.ino]
2024-12-24 adjust to correct ESP-NOW message length
    [UniRemote.ino, UniTestRcvr.ino]
2025-01-04 use calibration for my CYD
2025-01-05 UniRemoteCYD.ino reorganize with states and action buttons - compiles but not ready
2025-01-09 print out ESP-NOW error code values
    [testing02.ino]
2025-01-10 UniRemoteCYD.ino WIP err codes and LEDs
2025-01-23 UniRemote.ino add pin defs so it runs on CYD
2025-01-26 CYDbitBangCalibrate.ino start to merge RandomNerds calibrate with XPT2046_Bitbang
2025-01-27 CYDbitBangCalibrate add results of calibration
2025-01-27 UniRemoteCYD.ino correct original author date
    [UniRemoteCYD.ino]
2025-01-29 UniRemoteCYD.ino now works with calibrated Bitbang touchscreen; still working on RFID reader
2025-01-30 UniRemoteCYD.ino now operates RC522 RF IC Card Sensor; still some issue with ESP-NOW timeout
    [UniRemoteCYD.ino, WriteRFID_test.ino]
2025-01-30 UniRemoteCYD.ino now operates RC522 RF IC Card Sensor; USE_LV_TICK_SET_CB 0 and no issue with ESP-NOW timeout; don't know why
    [UniRemoteCYD.ino]
2025-02-01 UniRemoteCYD.ino improve error status reporting
    [UniRemoteCYD.ino]
2025-02-07 UniRemoteCYD.ino insert cyd_input_read.h XPT2046_Bitbang into *.ino
2025-02-08 UniRemoteCYD.ino moving calls to lvgl outside of ESP-NOW callback seems to fix lvgl timeout crashes
    [UniRemoteCYD.ino]
2025-02-18 fix typo in starting date
    [UniRemote.ino, UniTestRcvr.ino, testing02.ino]
2025-02-20 fix race condition UniRemoteRcvr.cpp and shorten fake dbg cmds in UniRemoteCYD.ino
    [UniRemoteCYD.ino, UniRemoteRcvrTemplate.ino]
2025-02-20 remove debug prints UniRemoteRcvr.cpp
2025-03-08 info on battery harness
2025-04-04 update schematics and drawings; modify WriteRFID_CYD.ino
    [Battery_Power.kicad_sch, UniRemoteCYD.kicad_pcb, UniRemoteCYD.kicad_sch]
2025-04-18 UniRemoteCYD.ino fix some warnings
    [UniRemoteCYD.ino, WriteRFID_CYD.ino]
2025-04-24 RFIDwriter schematic with WROOM-32D Devkit C
    [RFIDwriter.kicad_pcb, RFIDwriter.kicad_sch]
2025-04-25 WriteRFID variants: fix warnings
    [WriteRFID_CYD.ino]
2025-05-02 move ESP32_HW.md to ESP32D_HW.md
2025-05-08 KiCad V9.0.1
    [Battery_Power.kicad_sch, RFIDwriter.kicad_sch, UniRemoteCYD.kicad_sch]
2025-05-08 KiCad 9.0.1 RFIDwriter
2025-08-08 update schematic with connector type/details
    [UniRemoteCYD.kicad_sch]
